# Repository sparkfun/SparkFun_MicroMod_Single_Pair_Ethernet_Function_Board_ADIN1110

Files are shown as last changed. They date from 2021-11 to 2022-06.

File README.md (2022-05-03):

SparkFun_MicroMod_Single_Pair_Ethernet_Function_Board_ADIN1110
========================================

SparkFun MicroMod Single Pair Ethernet Function Board - ADIN1110 (https://www.sparkfun.com/products/19038)

[*SparkFun MicroMod Single Pair Ethernet Function Board - ADIN1110 (COM-19038)*](https://www.sparkfun.com/products/19038)

A MicroMod Function Board that provides Single Pair Ethernet (SPE) using the Analog Devices ADIN1110 10BASE-T1L Ethernet MAC-PHY Transceiver. The ADIN1110 is an ultra-low power, single-port Single Pair Ethernet transceiver. It features an integrated media access control (MAC) interface to allow for direct connections with a host controller via a serial peripheral interface (SPI) at 10 Mbp/s full duplex. To top it off, the specified cable reach for edge nodes is up to 1700 meters.

Repository Contents
-------------------

* **/Documents** - Datasheet
* **/Hardware** - Eagle design files (.brd, .sch)

Documentation
-------------

* **[Hookup Guide](https://learn.sparkfun.com/tutorials/micromod-single-pair-ethernet-function-board---adin1110-hookup-guide)** - A basic Hookup Guide to get started with the MicroMod Single Pair Ethernet Function Board - ADIN1110.
* **[SparkFun ADIN1110 Arduino Library](https://github.com/sparkfun/SparkFun_ADIN1110_Arduino_Libary)** - An Arduino library for the SparkFun MicroMod Single Pair Ethernet Function Board - ADIN1110.

Product Versions
----------------

* [COM-19038](https://www.sparkfun.com/products/19038) - Initial release

Version History
---------------

* v1.0 - Initial Release

License Information
-------------------

This product is _**open source**_! 

Please review the LICENSE.md file for license information. 

If you have any questions or concerns on licensing, please contact technical support on our [SparkFun forums](https://forum.sparkfun.com/viewforum.php?f=152).

Distributed as-is; no warranty is given.

- Your friends at SparkFun.

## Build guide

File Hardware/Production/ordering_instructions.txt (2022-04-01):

panel size, 128x137mm
PCB thickness, 0.8mm
number of layers, 4
bevel, Gold Fingers + 45° Finger Chamfered
soldermask color, Red
silkscreen color, White
oz copper, 1oz
finish, ENIG
stencils, top
pcs per panel, 6
min trace width, 0.1524mm / 0.0060in
min drill size, 0.3048mm / 0.0120in

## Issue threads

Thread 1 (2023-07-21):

Incompatibility with Esp32 MicroMod Processor Board

shulltronics, 2023-07-21:
Hi Sparkfun!

One of the SPE design challenge participants here :)  I have started working with the hardware kits that you sent us, and I have discovered an issue with the compatibility of this board with the Esp32 processor board, which is somewhat surprising seeing as you explicitly sell them together in a kit.

The INT pin for this function board is pulled high via R24, and is broken out to the PWM1 pad of the MicroMod connector (pin 47 I think). On the Esp32 side, pulling this pin high interferes with some bootstrapping stuff, making it such that the MCU cannot be programmed while the boards are connected.

I'm also creating an issue over on the ESP side, which I will link to here, because ultimately I think that GPIO12 (or any of the bootstrap pins) shouldn't be routed to the connector, for sake of compatibility with future function boards; however, you might also consider moving this pin to another spot on the MircoMod connector that is more suitable for interrupts, like one of the Gx bus pins, D0, D1, or I2C_INT (not used on this board).

I just wanted to make you all aware of this, and start a discussion for others who might run into this issue. Thanks!

alin180493, 2023-08-14:
Hi shulltronics,
I am part of the SPE challenge as well. I have raised this issue with sparkfun about 2 months ago.
After some back and forth emails with them, the conclusion was that they do not have a Engineer assigned for this project or the challenge and that  this is not very high on the priority list.
From my side, the "project" I am going to do for the challenge is to document my experience on a dev board worth 180 dollars which is not working with their demo codes.
A shame that we couldn't experience this new technology and supposedly for a challenge they do not have a person in charge.
PS: i am in this SPE challenge as a hobbyist that wants to do something cool with this tech and not as a professional embedded systems engineer.
PS2: The Harting connectors on the board are not compatible the supposedly standard Amphenol or TE connectors without mods...Amphenol and TE connectors are corss compatible.
Kind regards,
Alin

shulltronics, 2023-08-15:
Hi Alin,

Thanks for contributing to this issue :) It's sad that there is no one from SparkFun to help us with this -- especially considering an explicit issue like this with a product that they are current selling. Thanks for sharing about the connector compatibility.. part of my work on the challenge is a new hardware design so that is useful information.

alin180493, 2023-08-15:
Hi,

I have added some screenshot and pictures with the part numbers i have used to tryout the connector and also, to show the difference between them. You can see that on the spe board the connector has a shallower larger hole than the other 2 types of connector.

Feel free to use the images as reference if you find them helpful.

Kind regards,
Alin

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

lewispg228, 2023-08-16:
Hi Carsten and Alin,
Thanks for bringing this issue to our attention. Sorry for the inconvenience. We would recommend removing R22 from the design, or cutting the nearby trace to effectively remove the pullup from the circuit. Note, once this modification is done, then you will need to actively control that control pin on the processor board in your code. During your setup() make sure to include an extra line of code to enable that GPIO:

`pinMode(PWM1, INPUT_PULLUP);`

This will ensure that the function board's power vreg is enabled.

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

As for the cables, we only carry Harting cables and connectors, so we are unable to test with other branded connectors. We have our 0.5m cable available. Sorry we don't carry anything longer or the connector on it's own. We hope the modification you came up with to enlarge the hole will work well enough to get you through the project.

[https://www.sparkfun.com/products/19312](https://www.sparkfun.com/products/19312)

Hope this helps and let us know how it goes. -Pete Lewis

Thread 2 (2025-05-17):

ADIN1100 to ADIN1110 to give internet to MicroMOD?

bhupiister, 2025-05-17:
Is there a possibility to use ADIN1100 <==> ADIN1110 to give internet to MicroMOD boards?
Some sort of driver work can make it possible?

daveismith, 2025-05-22:
It's possible, but you need to have a an IP stack which SparkFun doesn't provide. If you have the right adaptor, see https://www.sg-electronic-systems.com/adin1110-linux-kernel/ for how to connect this as an interface to a Raspberry Pi. You can then set up the proper routing on a Pi. Alternatively Arrow sells (or maybe used to sell) a media converter that you can plug ethernet & USB-C for power on one side and get SPE out the other. See https://www.arrow.com/en/products/10base-t1l-mc/einfochips-limited.

For the embedded space, I got some sort of a driver for this working on the ESP32 (with esp-idf) back a few years ago but I wasn't sure about publishing it due to AD's licensing terms. Now it's likely not compatible with current versions of the ESP-IDF. If you use rust, the embassy framework has a driver that works for this and gives IP layer access (see https://docs.embassy.dev/embassy-net-adin1110/git/default/index.html) - note you need to solder jumper `SPICFG1`.

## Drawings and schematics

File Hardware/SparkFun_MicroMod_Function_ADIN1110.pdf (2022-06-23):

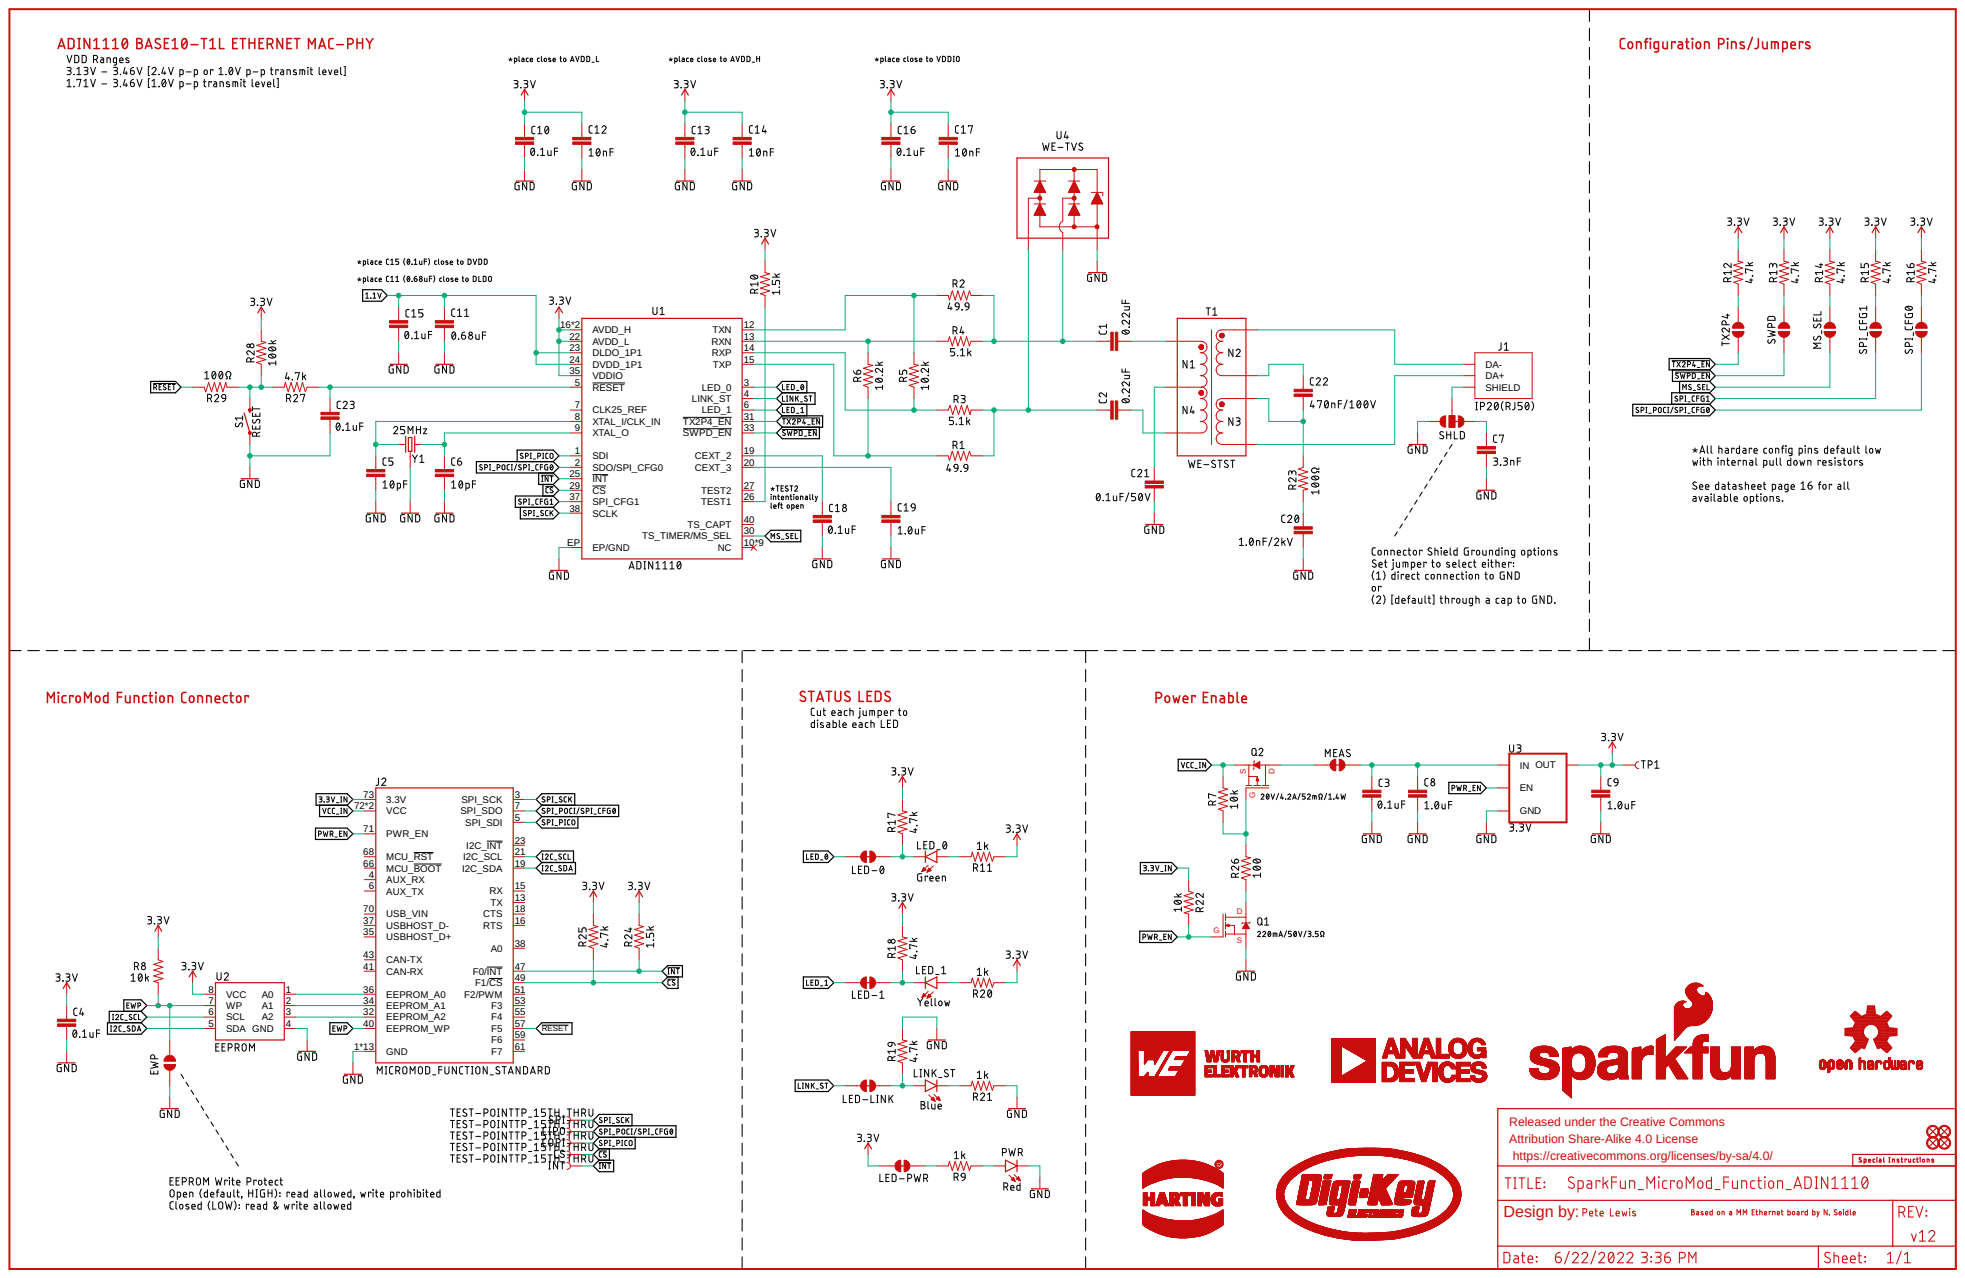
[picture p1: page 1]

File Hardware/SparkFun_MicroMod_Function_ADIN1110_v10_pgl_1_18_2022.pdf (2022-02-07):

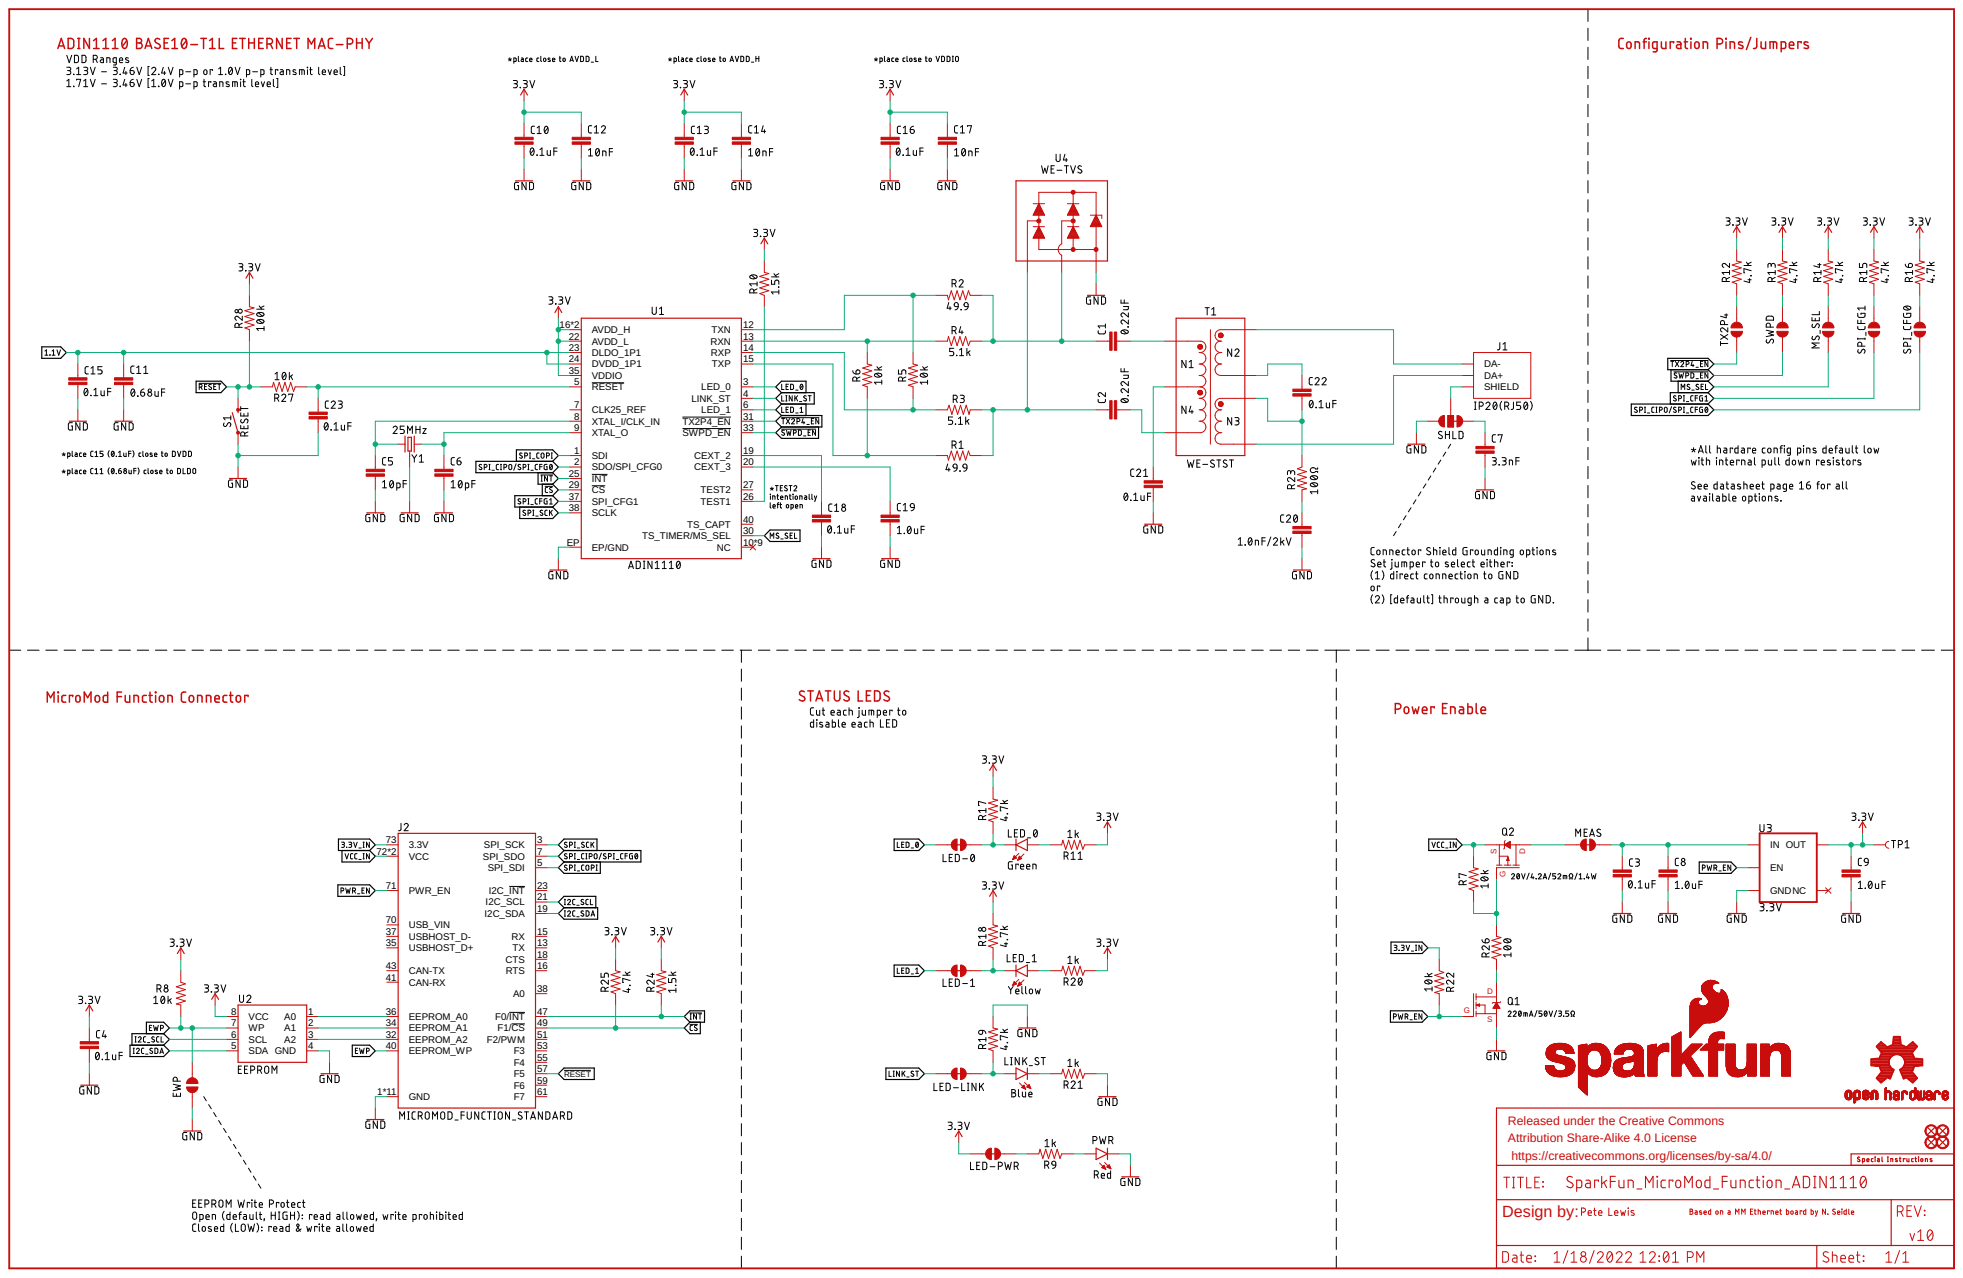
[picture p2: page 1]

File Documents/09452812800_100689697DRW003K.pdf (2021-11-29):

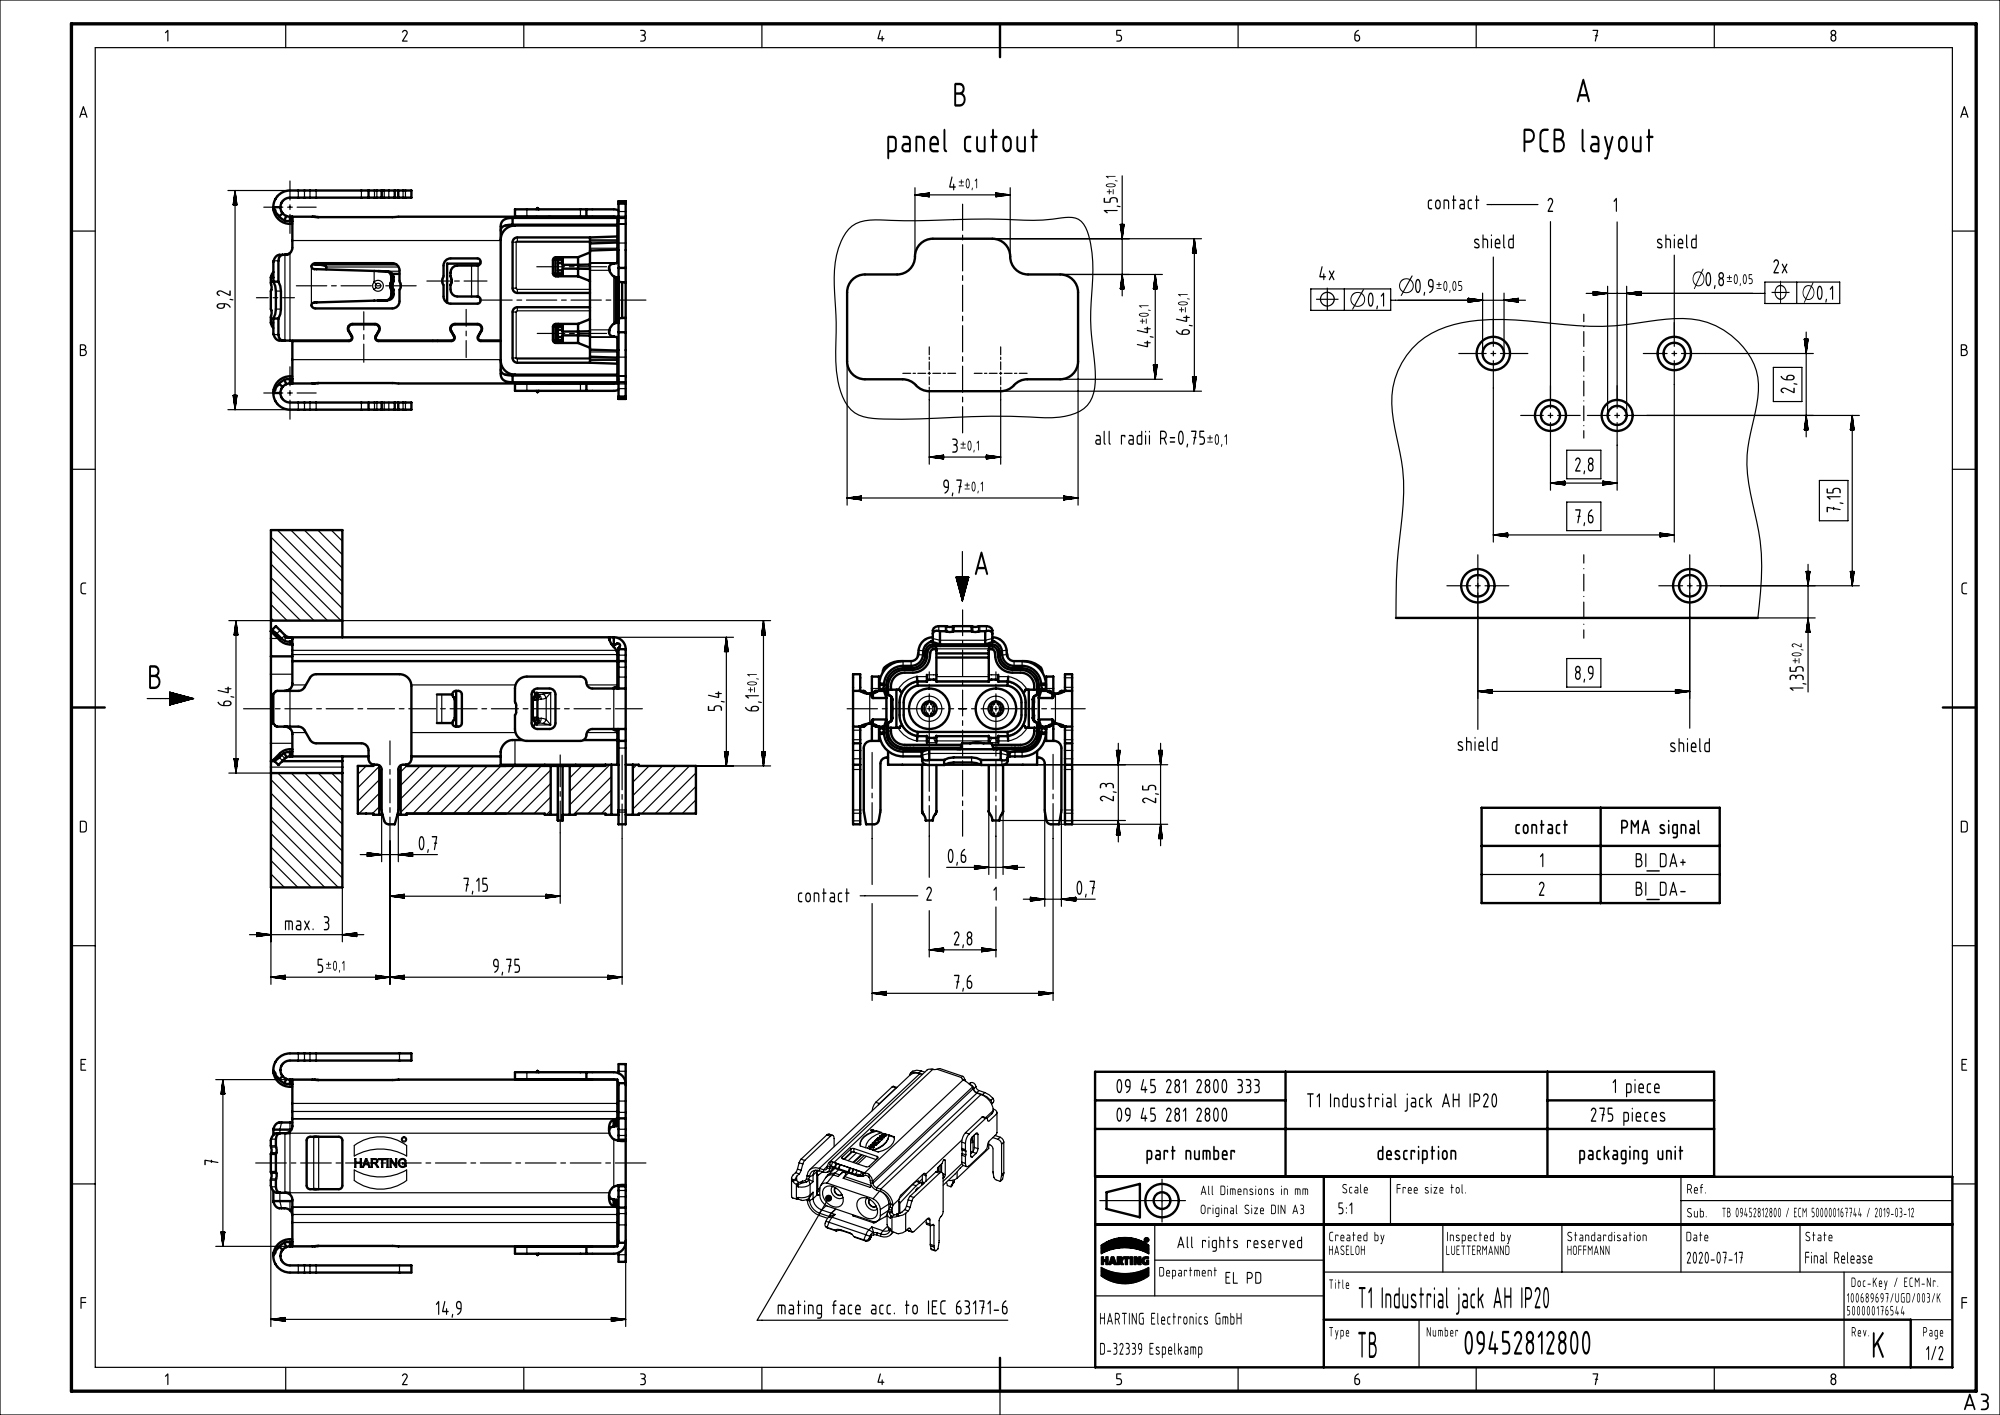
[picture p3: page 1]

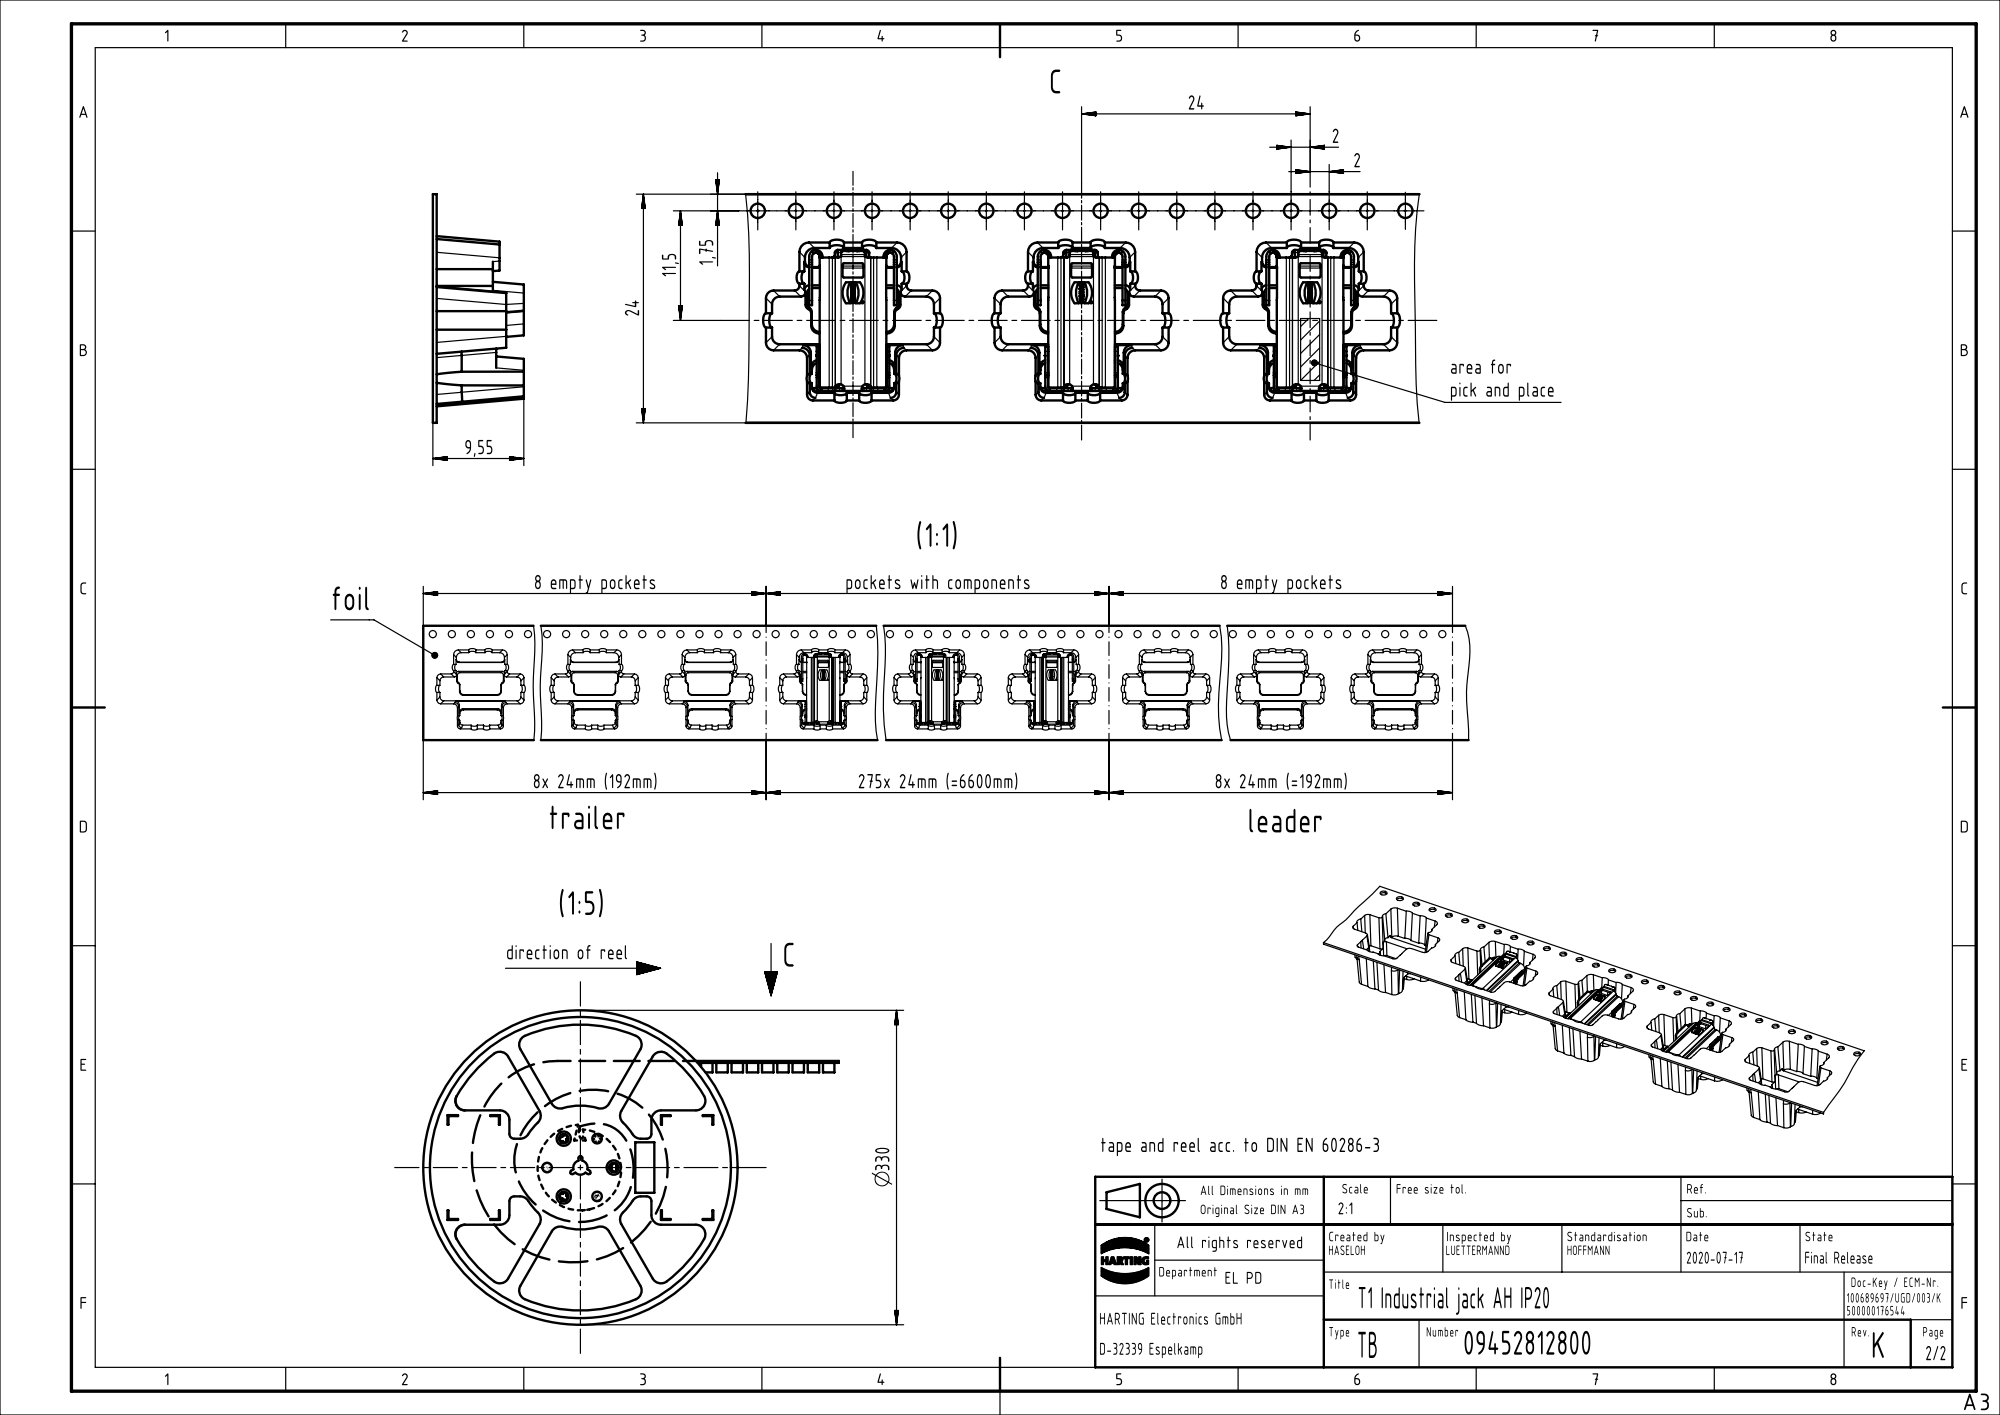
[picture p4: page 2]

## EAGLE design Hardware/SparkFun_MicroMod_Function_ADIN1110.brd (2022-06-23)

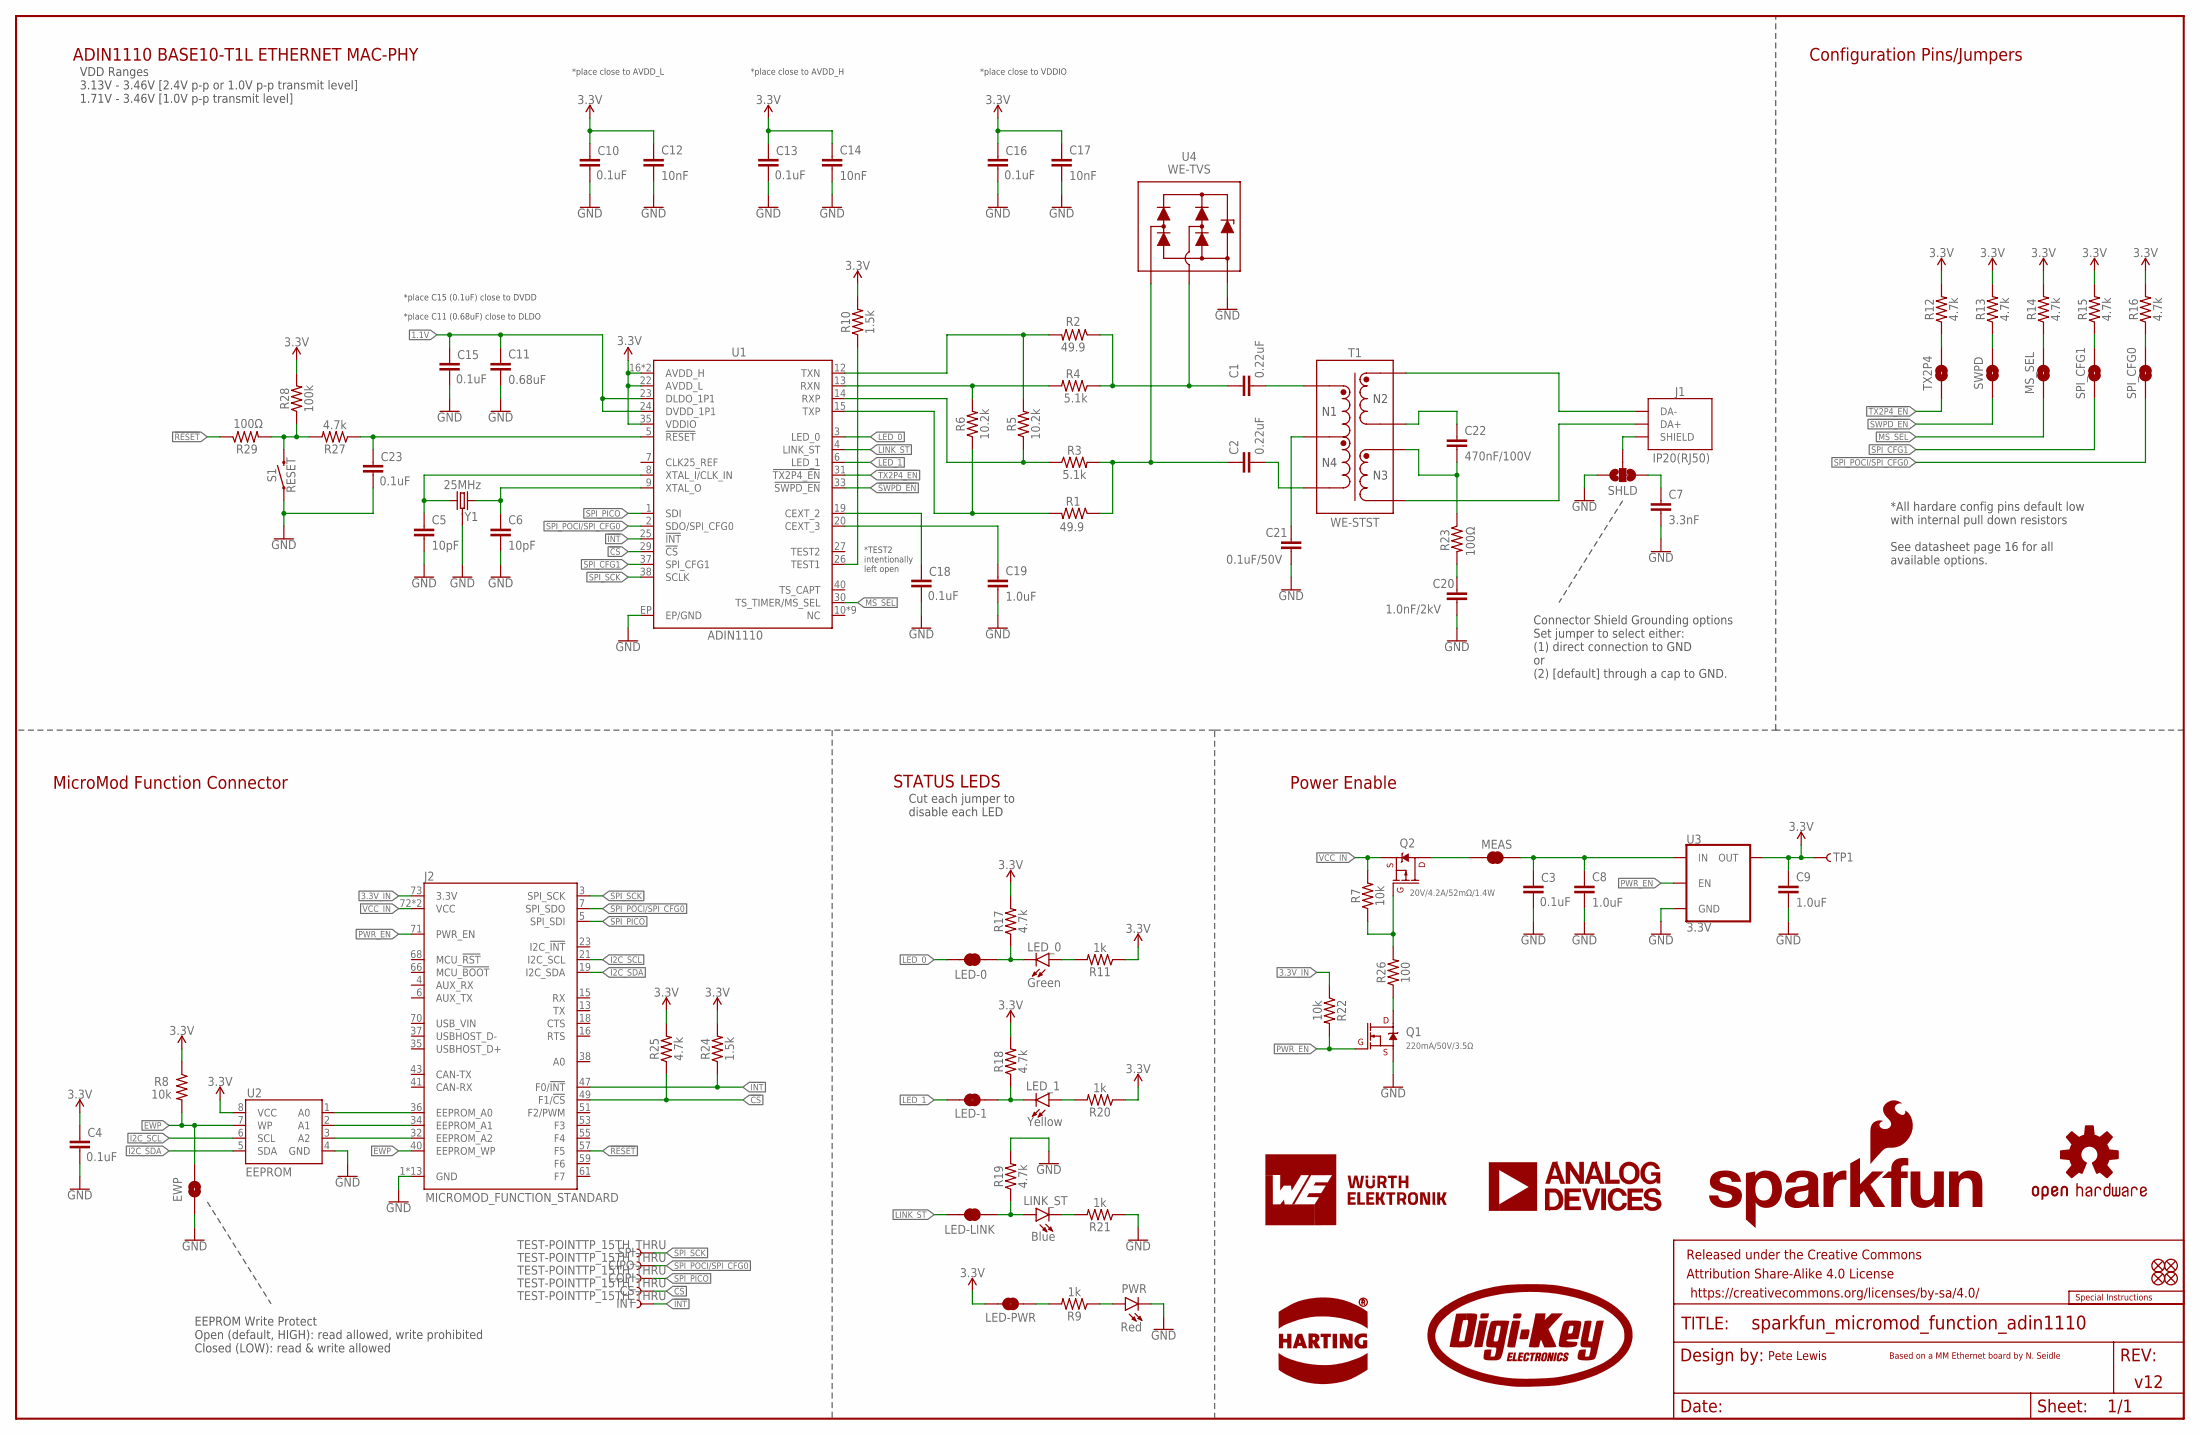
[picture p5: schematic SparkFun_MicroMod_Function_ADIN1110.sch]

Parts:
C1, C2: 0.22uF; 0603
C3, C4: 0.1uF; 0603
C5, C6: 10pF; 0603
C7: 3.3nF; 0603
C8, C9: 1.0uF; 0603
C10, C13, C15, C16, C18, C23: 0.1uF; 0402-TIGHT
C11: 0.68uF; 0603
C12, C14, C17: 10nF; 0402-TIGHT
C19: 1.0uF; 0402-TIGHT
C20: 1.0nF/2kV; 1206
C21: 0.1uF/50V; 0603
C22: 470nF/100V; 0805
CIPO: TEST-POINTTP_15TH_THRU; TP_15TH
COPI: TEST-POINTTP_15TH_THRU; TP_15TH
CS: TEST-POINTTP_15TH_THRU; TP_15TH
EWP: JUMPER-SMT_2_NO_SILK; SMT-JUMPER_2_NO_SILK
FD1, FD2, FD3, FD4: FIDUCIALUFIDUCIAL; FIDUCIAL-MICRO
FRAME1: FRAME-LEDGER; CREATIVE_COMMONS
INT: TEST-POINTTP_15TH_THRU; TP_15TH
J1: IP20(RJ50); T1_INDUSTRIAL_JACK_AH_IP20
J2: MICROMOD_FUNCTION_STANDARD; M.2-CARD-E-22_FUNCTION_STANDARD
LED-0, LED-1: JUMPER-SMT_2_NC_TRACE_SILK; SMT-JUMPER_2_NC_TRACE_SILK
LED-LINK: JUMPER-SMT_2_NC_TRACE_SILK; SMT-JUMPER_2_NC_TRACE_SILK
LED-PWR: JUMPER-SMT_2_NC_TRACE_SILK; SMT-JUMPER_2_NC_TRACE_SILK
LED_0: Green; LED-0603
LED_1: Yellow; LED-0603
LINK_ST: Blue; LED-0603
LOGO1: SFE_LOGO_NAME_FLAME.1_INCH; SFE_LOGO_NAME_FLAME_.1
LOGO2: SPECIAL_INSTRUCTIONS-ORDERING; ORDERING_INSTRUCTIONS
LOGO3: OSHW-LOGOMINI; OSHW-LOGO-MINI
MEAS: JUMPER-COMBO_2_NC_TRACE; COMBO-JUMPER_2_NC_TRACE
MS_SEL: JUMPER-SMT_2_NO_SILK; SMT-JUMPER_2_NO_SILK
PWR: Red; LED-0603
Q1: 220mA/50V/3.5Ω; SOT23-3
Q2: 20V/4.2A/52mΩ/1.4W; SOT23-3
R1, R2: 49.9; 0603
R3, R4: 5.1k; 0402-TIGHT
R5, R6: 10.2k; 0402-TIGHT
R7, R8, R22: 10k; 0603
R9, R11, R20, R21: 1k; 0402-TIGHT
R10, R24: 1.5k; 0603
R12, R13, R14, R15, R16, R17, R18, R19, R25: 4.7k; 0402-TIGHT
R23, R29: 100Ω; 0603
R26: 100; 0603
R27: 4.7k; 0603
R28: 100k; 0402-TIGHT
S1: RESET; TACTILE_SWITCH_SMD_5.2MM
SHLD: JUMPER-SMT_3_1-NC_TRACE_SILK; SMT-JUMPER_3_1-NC_TRACE_SILK
SPI: TEST-POINTTP_15TH_THRU; TP_15TH
SPI_CFG0, SPI_CFG1: JUMPER-SMT_2_NO_SILK; SMT-JUMPER_2_NO_SILK
SWPD: JUMPER-SMT_2_NO_SILK; SMT-JUMPER_2_NO_SILK
T1: WE-STST; WE_STST_TRANSFORMER_1:1_SMD_3.2X4.7MM_74930030
TP1: TEST-POINT3X4; PAD.03X.04
TX2P4: JUMPER-SMT_2_NO_SILK; SMT-JUMPER_2_NO_SILK
U1: ADIN1110; LFCSP-40
U2: EEPROM; SO08
U3: 3.3V; SOT23-5
U4: WE-TVS; WE_TVS_1.0X1.2MM
U$2: HARTING_LOGO; HARTING_LOGO_9MM
U$5: DIGIKEY_LOGO
U$19: WURTH_LOGO; WURTH_LOGO_9MM
U$33: ANALOG_DEVICES_LOGO; ANALOG_DEVICE_LOGO_9MM
Y1: 25MHz; CRYSTAL-SMD-2.0X1.6MM-WE

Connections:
1.1V: C11.1, C15.1, U1.23 (DLDO_1P1), U1.24 (DVDD_1P1)
3.3V: C4.1, C9.1, C10.1, C12.1, C13.1, C14.1, C16.1, C17.1, LED-PWR.2, R8.1, R10.2, R11.1, R12.2, R13.2, R14.2, R15.2, R16.2, R17.2, R18.2, R20.1, R24.2, R25.2, R28.2, TP1.1, U1.16 (AVDD_H), U1.17 (AVDD_H), U1.22 (AVDD_L), U1.35 (VDDIO), U2.8 (VCC), U3.5 (OUT)
3.3V_IN: J2.73 (3.3V), R22.1
!CS!: CS.1, J2.49 (F1/!CS!), R25.1, U1.29 (!CS!)
!INT!: INT.1, J2.47 (F0/!INT!), R24.1, U1.25 (!INT!)
!RESET!: J2.57 (F5), R29.1
!SWPD_EN!: SWPD.1, U1.33 (!SWPD_EN!)
!TX2P4_EN!: TX2P4.1, U1.31 (!TX2P4_EN!)
A0: J2.36 (EEPROM_A0), U2.1 (A0)
A1: J2.34 (EEPROM_A1), U2.2 (A1)
A2: J2.32 (EEPROM_A2), U2.3 (A2)
DA+: J1.1 (DA+), T1.7
DA-: J1.2 (DA-), T1.6
EWP: EWP.2, J2.40 (EEPROM_WP), R8.2, U2.7 (WP)
GND: C3.2, C4.2, C5.2, C6.2, C7.2, C8.2, C9.2, C10.2, C11.2, C12.2, C13.2, C14.2, C15.2, C16.2, C17.2, C18.2, C19.2, C20.2, C21.2, C23.2, EWP.1, J2.1 (GND), J2.2 (GND), J2.8 (GND), J2.33 (GND), J2.39 (GND), J2.45 (GND), J2.75 (GND), J2.GND1 (GND), J2.GND2 (GND), J2.GND3 (GND), J2.GND4 (GND), J2.GND5 (GND), J2.GND6 (GND), PWR.C, Q1.2 (S), R19.2, R21.1, S1.1, SHLD.1, U1.EP (EP/GND), U2.4 (GND), U3.2 (GND), U4.3, Y1.2 (GND), Y1.4 (GND)
I2C_SCL: J2.21 (I2C_SCL), U2.6 (SCL)
I2C_SDA: J2.19 (I2C_SDA), U2.5 (SDA)
LED_0: LED-0.2, U1.3 (LED_0)
LED_1: LED-1.2, U1.6 (LED_1)
LINK_ST: LED-LINK.2, U1.4 (LINK_ST)
MS_SEL: MS_SEL.1, U1.30 (TS_TIMER/MS_SEL)
unnamed: MEAS.1, MEAS.3 (1), Q2.3 (D)
unnamed: C3.1, C8.1, MEAS.2, MEAS.4 (2), U3.1 (IN)
unnamed: C21.1, T1.5
unnamed: C22.1, T1.4
unnamed: LED-LINK.1, LINK_ST.A, R19.1
unnamed: LED-1.1, LED_1.C, R18.1
unnamed: C22.2, R23.1, T1.3
unnamed: C20.1, R23.2
unnamed: LED-0.1, LED_0.C, R17.1
unnamed: Q1.3 (D), R26.1
unnamed: Q2.1 (G), R7.1, R26.2
unnamed: C5.1, U1.8 (XTAL_I/CLK_IN), Y1.1
unnamed: C23.1, R27.1, U1.5 (!RESET!)
unnamed: C6.1, U1.9 (XTAL_O), Y1.3 (2)
unnamed: R27.2, R28.1, R29.2, S1.3 (2)
unnamed: R10.1, U1.26 (TEST1)
unnamed: LED-PWR.1, R9.2
unnamed: PWR.A, R9.1
unnamed: C18.1, U1.19 (CEXT_2)
unnamed: C19.1, U1.20 (CEXT_3)
unnamed: LED_0.A, R11.2
unnamed: C1.1, R2.1, R4.1, U4.2, U4.5 (2)
unnamed: MS_SEL.2, R14.1
unnamed: R13.1, SWPD.2
unnamed: R12.1, TX2P4.2
unnamed: R16.1, SPI_CFG0.2
unnamed: R15.1, SPI_CFG1.2
unnamed: LED_1.A, R20.2
unnamed: C2.1, R1.1, R3.2, U4.1, U4.6 (1)
unnamed: C1.2, T1.1
unnamed: LINK_ST.C, R21.2
unnamed: C2.2, T1.2
unnamed: R4.2, R6.2, U1.13 (RXN)
unnamed: R3.1, R5.1, U1.14 (RXP)
unnamed: R1.2, R6.1, U1.15 (TXP)
unnamed: R2.2, R5.2, U1.12 (TXN)
unnamed: C7.1, SHLD.3
unnamed: J1.S1 (SHIELD), J1.S2 (SHIELD), J1.S3 (SHIELD), J1.S4 (SHIELD), SHLD.2
PWR_EN: J2.71 (PWR_EN), Q1.1 (G), R22.2, U3.3 (EN)
SPI_CFG1: SPI_CFG1.1, U1.37 (SPI_CFG1)
SPI_PICO: COPI.1, J2.5 (SPI_SDI), U1.1 (SDI)
SPI_POCI/SPI_CFG0: CIPO.1, J2.7 (SPI_SDO), SPI_CFG0.1, U1.2 (SDO/SPI_CFG0)
SPI_SCK: J2.3 (SPI_SCK), SPI.1, U1.38 (SCLK)
VCC_IN: J2.72 (VCC), J2.74 (VCC), Q2.2 (S), R7.2

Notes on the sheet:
MicroMod Function Connector
Pete Lewis
v12
ADIN1110 BASE10-T1L ETHERNET MAC-PHY
Power Enable
Based on a MM Ethernet board by N. Seidle
*place C15 (0.1uF) close to DVDD *place C11 (0.68uF) close to DLDO
*place close to AVDD_L
*place close to AVDD_H
*place close to VDDIO
*TEST2 intentionally left open
*All hardare config pins default low with internal pull down resistors See datasheet page 16 for all available options.
STATUS LEDS
Configuration Pins/Jumpers
VDD Ranges 3.13V - 3.46V [2.4V p-p or 1.0V p-p transmit level] 1.71V - 3.46V [1.0V p-p transmit level]
EEPROM Write Protect Open (default, HIGH): read allowed, write prohibited Closed (LOW): read & write allowed
Connector Shield Grounding options Set jumper to select either: (1) direct connection to GND or (2) [default] through a cap to GND.
Cut each jumper to disable each LED

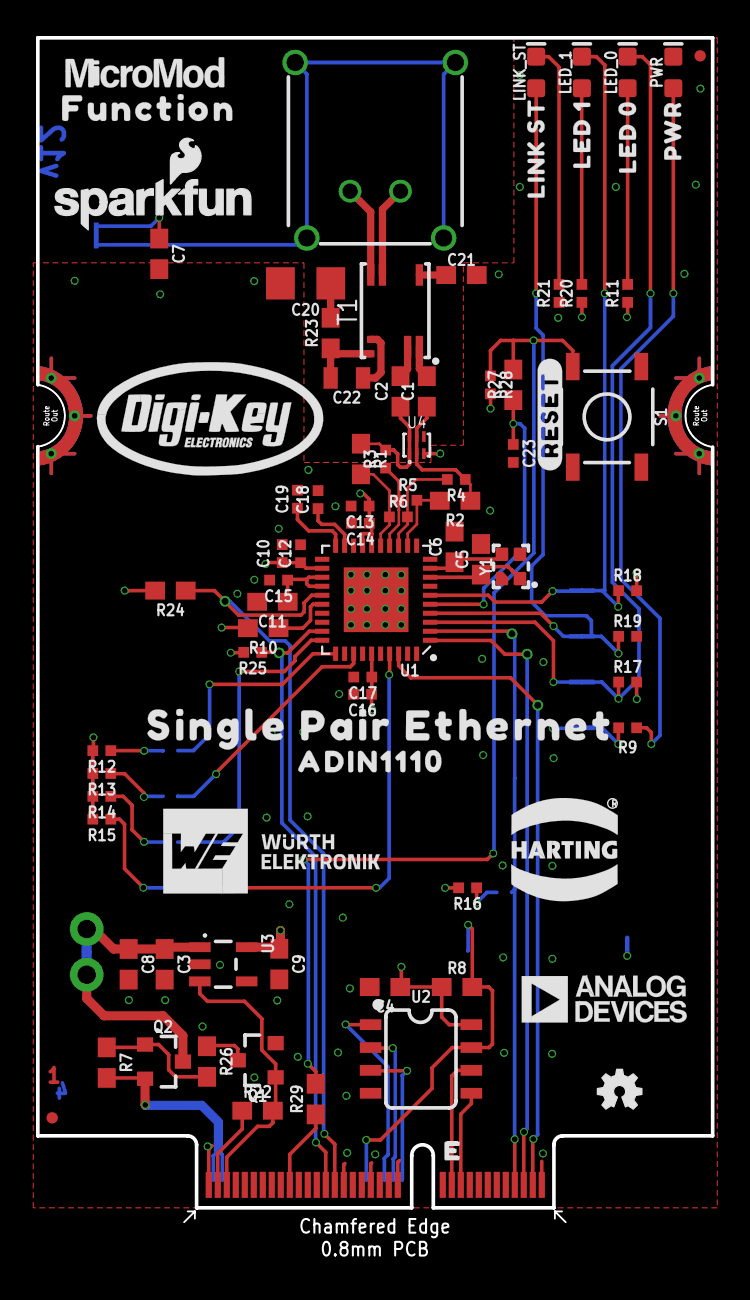
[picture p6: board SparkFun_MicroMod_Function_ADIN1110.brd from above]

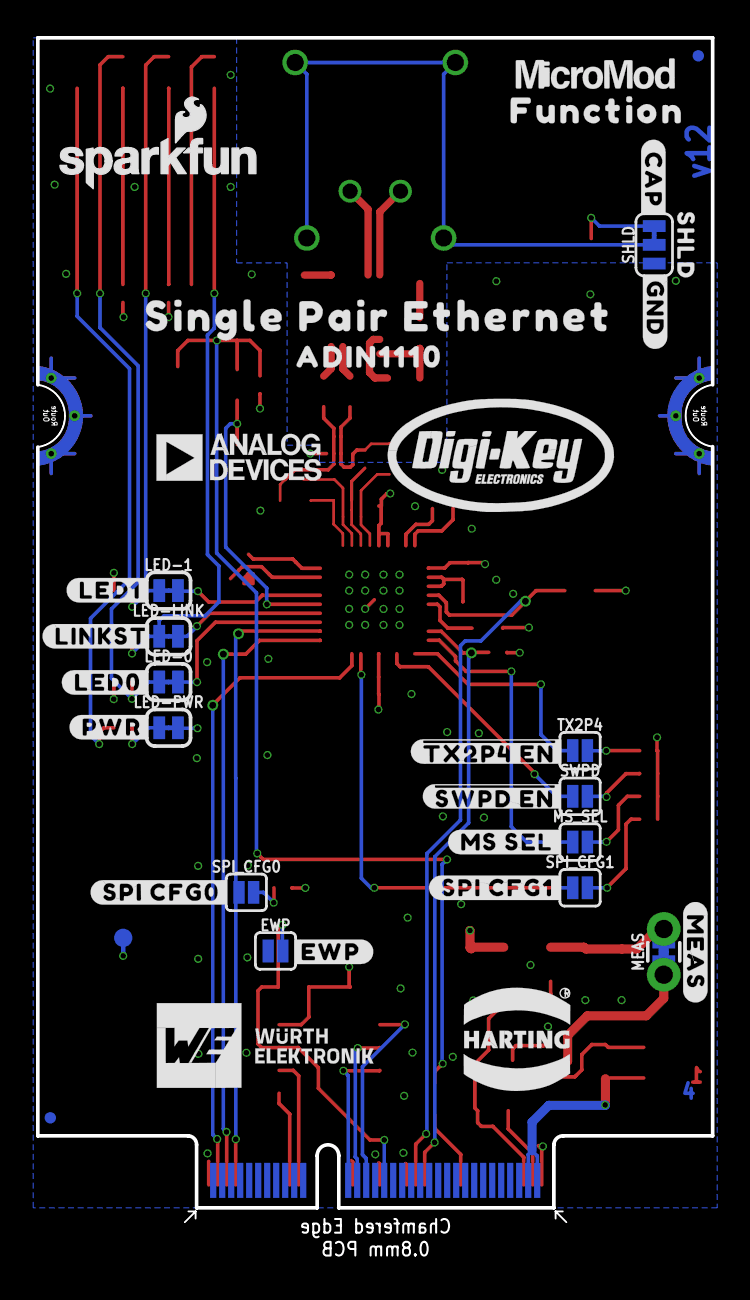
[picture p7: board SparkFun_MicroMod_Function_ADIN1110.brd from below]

Board: 4 copper layers, 37.5 x 65.8 mm, 129 parts (38 on the bottom side), 65 nets.

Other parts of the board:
U$1: #RESET#0
U$4, U$21: ADIN11100
U$6: #PWR#19
U$7: PWR0
U$8: SHLD11
U$9: #EWP#18
U$10: #LED0#20
U$11: #GND#16
U$12: #CAP#17
U$13: ##TX2P4_EN##4
U$14: #SPI_CFG1#0
U$15: #MS_SEL#2
U$16: #SPI_CFG0#0
U$17, U$18: SINGLE_PAIR_ETHERNET0
U$20: ANALOG_DEVICE_LOGO_9MM
U$22: ##SWPD_EN##4
U$23: LED_03
U$24, U$26: FUNCTION0
U$25: LED_14
U$27: LINK_ST15
U$28: #MEAS#3
U$29: #LED1#21
U$30: HARTING_LOGO_9MM
U$31: #LINKST#2
U$32: WURTH_LOGO_9MM
U$34: DIGIKEY_LOGO
U$35: SFE_LOGO_NAME_FLAME_.1
U$37, U$63: MICROMOD_LOGO_.35

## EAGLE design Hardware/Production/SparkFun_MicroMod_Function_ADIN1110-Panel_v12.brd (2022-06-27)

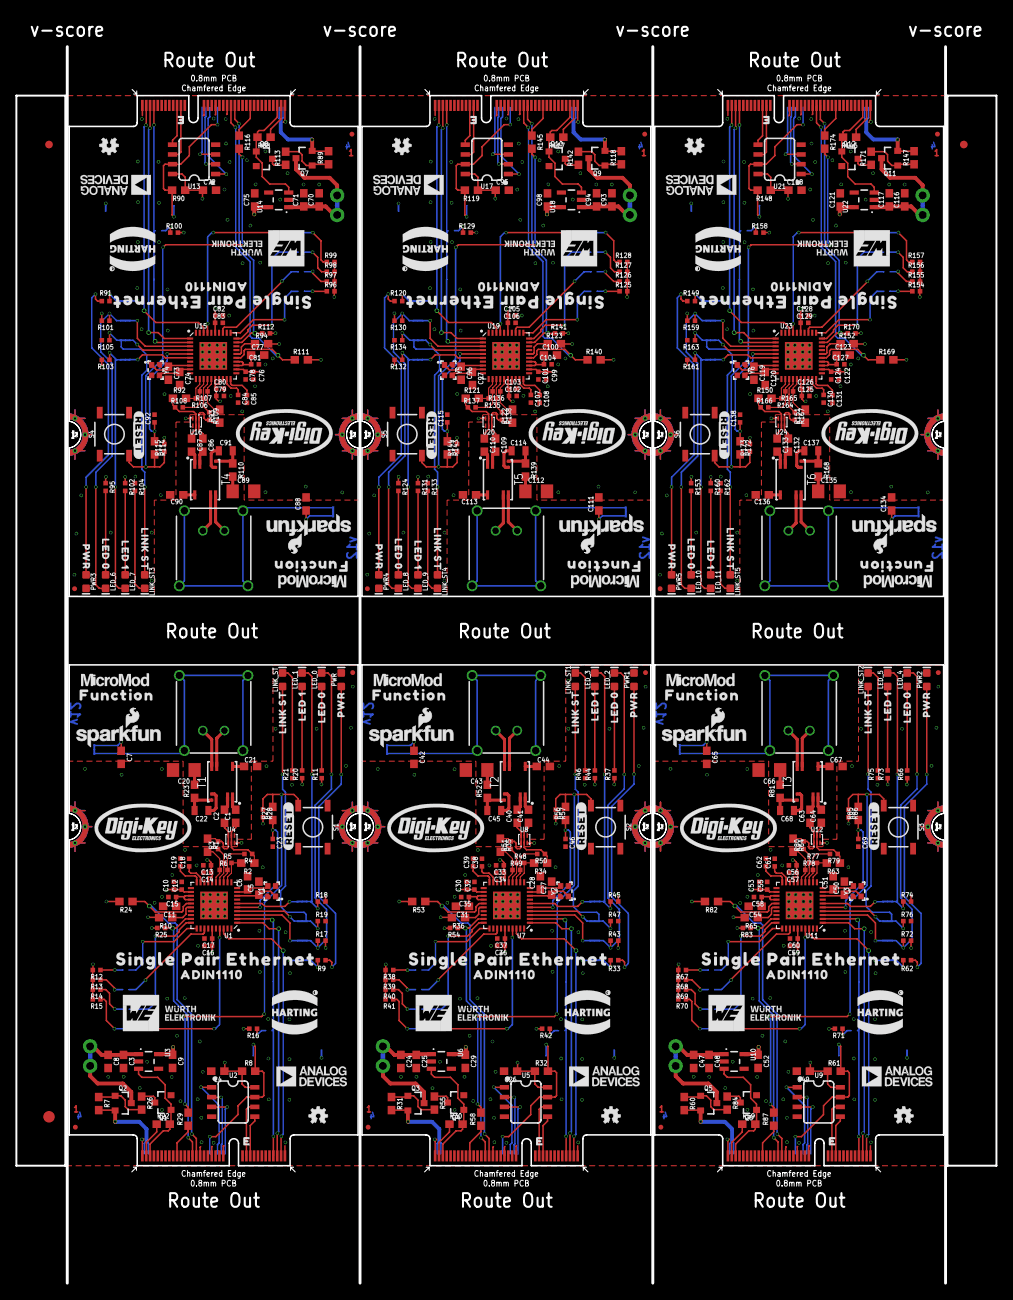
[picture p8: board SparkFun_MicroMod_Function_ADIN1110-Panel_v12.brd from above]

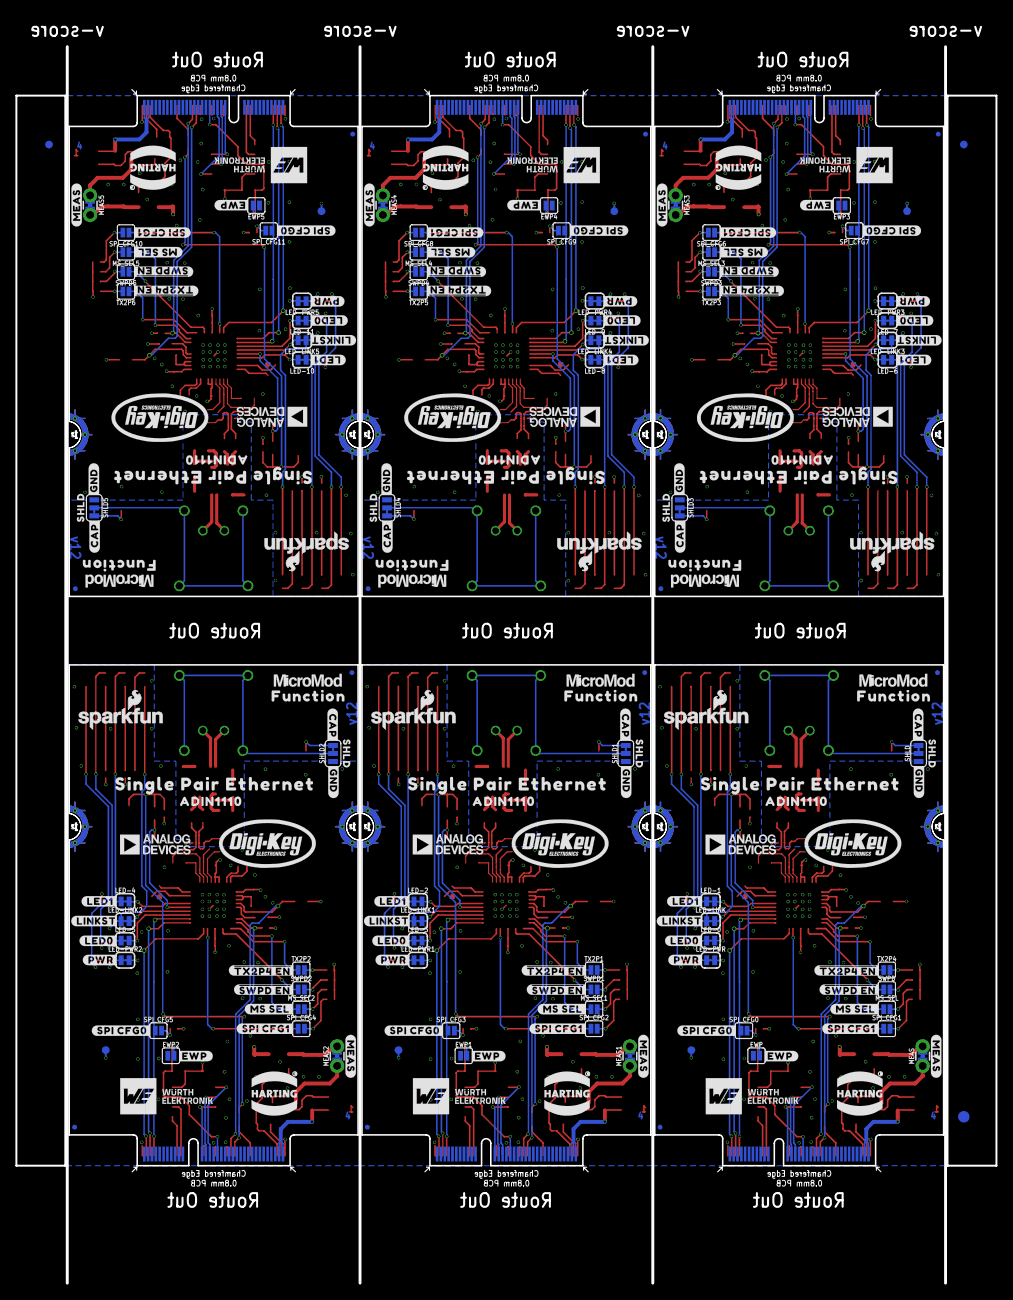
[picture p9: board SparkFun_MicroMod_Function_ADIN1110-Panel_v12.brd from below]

Board: 4 copper layers, 127.2 x 160.5 mm, 768 parts (231 on the bottom side), 390 nets.

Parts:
C1, C2, C40, C41, C63, C64, C86, C87, C109, C110, C132, C133: 0.22uF; 0603
C3, C4, C25, C26, C48, C49, C71, C72, C94, C95, C117, C118: 0.1uF; 0603
C5, C6, C27, C28, C50, C51, C73, C74, C96, C97, C119, C120: 10pF; 0603
C7, C42, C65, C88, C111, C134: 3.3nF; 0603
C8, C9, C24, C29, C47, C52, C70, C75, C93, C98, C116, C121: 1.0uF; 0603
C10, C13, C15, C16, C18, C23, C30, C33, C35, C36, C38, C46, C53, C56, C58, C59, C61, C69, C76, C79, C81, C82, C84, C92, C99, C102, C104, C105, C107, C115, C122, C125, C127, C128, C130, C138: 0.1uF; 0402-TIGHT
C11, C31, C54, C77, C100, C123: 0.68uF; 0603
C12, C14, C17, C32, C34, C37, C55, C57, C60, C78, C80, C83, C101, C103, C106, C124, C126, C129: 10nF; 0402-TIGHT
C19, C39, C62, C85, C108, C131: 1.0uF; 0402-TIGHT
C20, C43, C66, C89, C112, C135: 1.0nF/2kV; 1206
C21, C44, C67, C90, C113, C136: 0.1uF/50V; 0603
C22, C45, C68, C91, C114, C137: 470nF/100V; 0805
CIPO, CIPO1, CIPO2, CIPO3, CIPO4, CIPO5: TEST-POINTTP_15TH_THRU; TP_15TH
COPI, COPI1, COPI2, COPI3, COPI4, COPI5: TEST-POINTTP_15TH_THRU; TP_15TH
CS, CS1, CS2, CS3, CS4, CS5: TEST-POINTTP_15TH_THRU; TP_15TH
E$1, E$2, E$3, E$4: FIDUCIAL-1X2
E$5, E$6: FIDUCIAL-1.5X3
EWP, EWP1, EWP2, EWP3, EWP4, EWP5: JUMPER-SMT_2_NO_SILK; SMT-JUMPER_2_NO_SILK
FD1, FD2, FD3, FD4, FD5, FD6, FD7, FD8, FD9, FD10, FD11, FD12, FD13, FD14, FD15, FD16, FD17, FD18, FD19, FD20, FD21, FD22, FD23, FD24: FIDUCIALUFIDUCIAL; FIDUCIAL-MICRO
INT, INT1, INT2, INT3, INT4, INT5: TEST-POINTTP_15TH_THRU; TP_15TH
J1, J4, J6, J8, J10, J12: IP20(RJ50); T1_INDUSTRIAL_JACK_AH_IP20
J2, J3, J5, J7, J9, J11: MICROMOD_FUNCTION_STANDARD; M.2-CARD-E-22_FUNCTION_STANDARD
LED-0, LED-1, LED-2, LED-3, LED-4, LED-5, LED-6, LED-7, LED-8, LED-9, LED-10, LED-11: JUMPER-SMT_2_NC_TRACE_SILK; SMT-JUMPER_2_NC_TRACE_SILK
LED-LINK, LED-LINK1, LED-LINK2, LED-LINK3, LED-LINK4, LED-LINK5: JUMPER-SMT_2_NC_TRACE_SILK; SMT-JUMPER_2_NC_TRACE_SILK
LED-PWR, LED-PWR1, LED-PWR2, LED-PWR3, LED-PWR4, LED-PWR5: JUMPER-SMT_2_NC_TRACE_SILK; SMT-JUMPER_2_NC_TRACE_SILK
LED_0, LED_2, LED_4, LED_6, LED_8, LED_10: Green; LED-0603
LED_1, LED_3, LED_5, LED_7, LED_9, LED_11: Yellow; LED-0603
LINK_ST, LINK_ST1, LINK_ST2, LINK_ST3, LINK_ST4, LINK_ST5: Blue; LED-0603
LOGO1, LOGO4, LOGO6, LOGO8, LOGO10, LOGO12: SFE_LOGO_NAME_FLAME.1_INCH; SFE_LOGO_NAME_FLAME_.1
LOGO2, LOGO3, LOGO5, LOGO7, LOGO9, LOGO11: OSHW-LOGOMINI; OSHW-LOGO-MINI
MEAS, MEAS1, MEAS2, MEAS3, MEAS4, MEAS5: JUMPER-COMBO_2_NC_TRACE; COMBO-JUMPER_2_NC_TRACE
MS_SEL, MS_SEL1, MS_SEL2, MS_SEL3, MS_SEL4, MS_SEL5: SMT-JUMPER_2_NO_SILK
PWR, PWR1, PWR2, PWR3, PWR4, PWR5: Red; LED-0603
Q1, Q4, Q6, Q8, Q10, Q12: 220mA/50V/3.5Ω; SOT23-3
Q2, Q3, Q5, Q7, Q9, Q11: 20V/4.2A/52mΩ/1.4W; SOT23-3
R1, R2, R34, R35, R63, R64, R92, R93, R121, R122, R150, R151: 49.9; 0603
R3, R4, R50, R51, R79, R80, R108, R109, R137, R138, R166, R167: 5.1k; 0402-TIGHT
R5, R6, R48, R49, R77, R78, R106, R107, R135, R136, R164, R165: 10.2k; 0402-TIGHT
R7, R8, R22, R30, R31, R32, R59, R60, R61, R88, R89, R90, R117, R118, R119, R146, R147, R148: 10k; 0603
R9, R11, R20, R21, R33, R37, R44, R46, R62, R66, R73, R75, R91, R95, R102, R104, R120, R124, R131, R133, R149, R153, R160, R162: 1k; 0402-TIGHT
R10, R24, R36, R53, R65, R82, R94, R111, R123, R140, R152, R169: 1.5k; 0603
R12, R13, R14, R15, R16, R17, R18, R19, R25, R38, R39, R40, R41, R42, R43, R45, R47, R54, R67, R68, R69, R70, R71, R72, R74, R76, R83, R96, R97, R98, R99, R100, R101, R103, R105, R112, R125, R126, R127, R128, R129, R130, R132, R134, R141, R154, R155, R156, R157, R158, R159, R161, R163, R170: 4.7k; 0402-TIGHT
R23, R29, R52, R58, R81, R87, R110, R116, R139, R145, R168, R174: 100Ω; 0603
R26, R55, R84, R113, R142, R171: 100; 0603
R27, R56, R85, R114, R143, R172: 4.7k; 0603
R28, R57, R86, R115, R144, R173: 100k; 0402-TIGHT
S1, S2, S3, S4, S5, S6: RESET; TACTILE_SWITCH_SMD_5.2MM
SHLD, SHLD1, SHLD2, SHLD3, SHLD4, SHLD5: SMT-JUMPER_3_1-NC_TRACE_SILK
SPI, SPI1, SPI2, SPI3, SPI4, SPI5: TEST-POINTTP_15TH_THRU; TP_15TH
SPI_CFG0, SPI_CFG1, SPI_CFG2, SPI_CFG3, SPI_CFG4, SPI_CFG5, SPI_CFG6, SPI_CFG7, SPI_CFG8, SPI_CFG9, SPI_CFG10, SPI_CFG11: SMT-JUMPER_2_NO_SILK
SWPD, SWPD1, SWPD2, SWPD3, SWPD4, SWPD5: SMT-JUMPER_2_NO_SILK
T1, T2, T3, T4, T5, T6: WE-STST; WE_STST_TRANSFORMER_1:1_SMD_3.2X4.7MM_74930030
TP1, TP2, TP3, TP4, TP5, TP6: TEST-POINT3X4; PAD.03X.04
TX2P1, TX2P2, TX2P3, TX2P4, TX2P5, TX2P6: SMT-JUMPER_2_NO_SILK
U1, U7, U11, U15, U19, U23: ADIN1110; LFCSP-40
U2, U5, U9, U13, U17, U21: EEPROM; SO08
U3, U6, U10, U14, U18, U22: 3.3V; SOT23-5
U4, U8, U12, U16, U20, U24: WE-TVS; WE_TVS_1.0X1.2MM
U$1, U$42, U$79, U$115, U$151, U$187: #RESET#0
U$2, U$71, U$107, U$143, U$179, U$215: HARTING_LOGO; HARTING_LOGO_9MM
U$3, U$36, U$37, U$63, U$73, U$74, U$109, U$110, U$145, U$146, U$181, U$182: MICROMOD_LOGO_.35
U$4, U$21, U$41, U$47, U$78, U$84, U$114, U$120, U$150, U$156, U$186, U$192: ADIN11100
U$5, U$69, U$105, U$141, U$177, U$213: DIGIKEY_LOGO
U$6, U$55, U$92, U$128, U$164, U$200: #PWR#19
U$7, U$39, U$76, U$112, U$148, U$184: PWR0
U$8, U$43, U$80, U$116, U$152, U$188: SHLD11
U$9, U$54, U$91, U$127, U$163, U$199: #EWP#18
U$10, U$56, U$93, U$129, U$165, U$201: #LED0#20
U$11, U$52, U$89, U$125, U$161, U$197: #GND#16
U$12, U$53, U$90, U$126, U$162, U$198: #CAP#17
U$13, U$59, U$96, U$132, U$168, U$204: ##TX2P4_EN##4
U$14, U$44, U$81, U$117, U$153, U$189: #SPI_CFG1#0
U$15, U$45, U$82, U$118, U$154, U$190: #MS_SEL#2
U$16, U$46, U$83, U$119, U$155, U$191: #SPI_CFG0#0
U$17, U$18, U$61, U$62, U$98, U$99, U$134, U$135, U$170, U$171, U$206, U$207: SINGLE_PAIR_ETHERNET0
U$19, U$72, U$108, U$144, U$180, U$216: WURTH_LOGO; WURTH_LOGO_9MM
U$20, U$64, U$100, U$136, U$172, U$208: ANALOG_DEVICE_LOGO_9MM
U$22, U$60, U$97, U$133, U$169, U$205: ##SWPD_EN##4
U$23, U$49, U$86, U$122, U$158, U$194: LED_03
U$24, U$26, U$40, U$48, U$77, U$85, U$113, U$121, U$149, U$157, U$185, U$193: FUNCTION0
U$25, U$50, U$87, U$123, U$159, U$195: LED_14
U$27, U$51, U$88, U$124, U$160, U$196: LINK_ST15
U$28, U$38, U$75, U$111, U$147, U$183: #MEAS#3
U$29, U$57, U$94, U$130, U$166, U$202: #LED1#21
U$30, U$65, U$101, U$137, U$173, U$209: HARTING_LOGO_9MM
U$31, U$58, U$95, U$131, U$167, U$203: #LINKST#2
U$32, U$66, U$102, U$138, U$174, U$210: WURTH_LOGO_9MM
U$33, U$70, U$106, U$142, U$178, U$214: ANALOG_DEVICES_LOGO; ANALOG_DEVICE_LOGO_9MM
U$34, U$67, U$103, U$139, U$175, U$211: DIGIKEY_LOGO
U$35, U$68, U$104, U$140, U$176, U$212: SFE_LOGO_NAME_FLAME_.1
Y1, Y2, Y3, Y4, Y5, Y6: 25MHz; CRYSTAL-SMD-2.0X1.6MM-WE

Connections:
1.1V: C11.1, C15.1, U1.23, U1.24
1.1V1: C31.1, C35.1, U7.23, U7.24
1.1V2: C54.1, C58.1, U11.23, U11.24
1.1V3: C77.1, C81.1, U15.23, U15.24
1.1V4: C100.1, C104.1, U19.23, U19.24
1.1V5: C123.1, C127.1, U23.23, U23.24
3.3V: C4.1, C9.1, C10.1, C12.1, C13.1, C14.1, C16.1, C17.1, LED-PWR.2, R8.1, R10.2, R11.1, R12.2, R13.2, R14.2, R15.2, R16.2, R17.2, R18.2, R20.1, R24.2, R25.2, R28.2, TP1.1, U1.16, U1.17, U1.22, U1.35, U2.8, U3.5
3.3V1: C26.1, C29.1, C30.1, C32.1, C33.1, C34.1, C36.1, C37.1, LED-PWR1.2, R32.1, R36.2, R37.1, R38.2, R39.2, R40.2, R41.2, R42.2, R43.2, R44.1, R45.2, R53.2, R54.2, R57.2, TP2.1, U5.8, U6.5, U7.16, U7.17, U7.22, U7.35
3.3V2: C49.1, C52.1, C53.1, C55.1, C56.1, C57.1, C59.1, C60.1, LED-PWR2.2, R61.1, R65.2, R66.1, R67.2, R68.2, R69.2, R70.2, R71.2, R72.2, R73.1, R74.2, R82.2, R83.2, R86.2, TP3.1, U9.8, U10.5, U11.16, U11.17, U11.22, U11.35
3.3V3: C72.1, C75.1, C76.1, C78.1, C79.1, C80.1, C82.1, C83.1, LED-PWR3.2, R90.1, R94.2, R95.1, R96.2, R97.2, R98.2, R99.2, R100.2, R101.2, R102.1, R103.2, R111.2, R112.2, R115.2, TP4.1, U13.8, U14.5, U15.16, U15.17, U15.22, U15.35
3.3V4: C95.1, C98.1, C99.1, C101.1, C102.1, C103.1, C105.1, C106.1, LED-PWR4.2, R119.1, R123.2, R124.1, R125.2, R126.2, R127.2, R128.2, R129.2, R130.2, R131.1, R132.2, R140.2, R141.2, R144.2, TP5.1, U17.8, U18.5, U19.16, U19.17, U19.22, U19.35
3.3V5: C118.1, C121.1, C122.1, C124.1, C125.1, C126.1, C128.1, C129.1, LED-PWR5.2, R148.1, R152.2, R153.1, R154.2, R155.2, R156.2, R157.2, R158.2, R159.2, R160.1, R161.2, R169.2, R170.2, R173.2, TP6.1, U21.8, U22.5, U23.16, U23.17, U23.22, U23.35
3.3V_IN: J2.73, R22.1
3.3V_IN1: J3.73, R30.1
3.3V_IN2: J5.73, R59.1
3.3V_IN3: J7.73, R88.1
3.3V_IN4: J9.73, R117.1
3.3V_IN5: J11.73, R146.1
!CS!: CS.1, J2.49, R25.1, U1.29
!CS!1: CS1.1, J3.49, R54.1, U7.29
!CS!2: CS2.1, J5.49, R83.1, U11.29
!CS!3: CS3.1, J7.49, R112.1, U15.29
!CS!4: CS4.1, J9.49, R141.1, U19.29
!CS!5: CS5.1, J11.49, R170.1, U23.29
!INT!: INT.1, J2.47, R24.1, U1.25
!INT!1: INT1.1, J3.47, R53.1, U7.25
!INT!2: INT2.1, J5.47, R82.1, U11.25
!INT!3: INT3.1, J7.47, R111.1, U15.25
!INT!4: INT4.1, J9.47, R140.1, U19.25
!INT!5: INT5.1, J11.47, R169.1, U23.25
!RESET!: J2.57, R29.1
!RESET!1: J3.57, R58.1
!RESET!2: J5.57, R87.1
!RESET!3: J7.57, R116.1
!RESET!4: J9.57, R145.1
!RESET!5: J11.57, R174.1
!SWPD_EN!: SWPD.1, U1.33
!SWPD_EN!1: SWPD1.1, U7.33
!SWPD_EN!2: SWPD2.1, U11.33
!SWPD_EN!3: SWPD3.1, U15.33
!SWPD_EN!4: SWPD4.1, U19.33
!SWPD_EN!5: SWPD5.1, U23.33
!TX2P4_EN!: TX2P4.1, U1.31
!TX2P4_EN!1: TX2P1.1, U7.31
!TX2P4_EN!2: TX2P2.1, U11.31
!TX2P4_EN!3: TX2P3.1, U15.31
!TX2P4_EN!4: TX2P5.1, U19.31
!TX2P4_EN!5: TX2P6.1, U23.31
A0: J2.36, U2.1
A1: J2.34, U2.2
A2: J2.32, U2.3
A3: J3.36, U5.1
A4: J3.32, U5.3
A5: J3.34, U5.2
A6: J5.36, U9.1
A7: J5.32, U9.3
A8: J5.34, U9.2
A9: J7.36, U13.1
A10: J7.32, U13.3
A11: J7.34, U13.2
A12: J9.36, U17.1
A13: J9.32, U17.3
A14: J9.34, U17.2
A15: J11.36, U21.1
A16: J11.32, U21.3
A17: J11.34, U21.2
DA+: J1.1, T1.7
DA+1: J4.1, T2.7
DA+2: J6.1, T3.7
DA+3: J8.1, T4.7
DA+4: J10.1, T5.7
DA+5: J12.1, T6.7
DA-: J1.2, T1.6
DA-1: J4.2, T2.6
DA-2: J6.2, T3.6
DA-3: J8.2, T4.6
DA-4: J10.2, T5.6
DA-5: J12.2, T6.6
EWP: EWP.2, J2.40, R8.2, U2.7
EWP1: EWP1.2, J3.40, R32.2, U5.7
EWP2: EWP2.2, J5.40, R61.2, U9.7
EWP3: EWP3.2, J7.40, R90.2, U13.7
EWP4: EWP4.2, J9.40, R119.2, U17.7
EWP5: EWP5.2, J11.40, R148.2, U21.7
GND: C3.2, C4.2, C5.2, C6.2, C7.2, C8.2, C9.2, C10.2, C11.2, C12.2, C13.2, C14.2, C15.2, C16.2, C17.2, C18.2, C19.2, C20.2, C21.2, C23.2, EWP.1, J2.1, J2.2, J2.8, J2.33, J2.39, J2.45, J2.75, J2.GND1, J2.GND2, J2.GND3, J2.GND4, J2.GND5, J2.GND6, PWR.C, Q1.2, R19.2, R21.1, S1.1, SHLD.1, U1.EP, U2.4, U3.2, U4.3, Y1.2, Y1.4
GND1: C24.2, C25.2, C26.2, C27.2, C28.2, C29.2, C30.2, C31.2, C32.2, C33.2, C34.2, C35.2, C36.2, C37.2, C38.2, C39.2, C42.2, C43.2, C44.2, C46.2, EWP1.1, J3.1, J3.2, J3.8, J3.33, J3.39, J3.45, J3.75, J3.GND1, J3.GND2, J3.GND3, J3.GND4, J3.GND5, J3.GND6, PWR1.C, Q4.2, R46.1, R47.2, S2.1, SHLD1.1, U5.4, U6.2, U7.EP, U8.3, Y2.2, Y2.4
GND2: C47.2, C48.2, C49.2, C50.2, C51.2, C52.2, C53.2, C54.2, C55.2, C56.2, C57.2, C58.2, C59.2, C60.2, C61.2, C62.2, C65.2, C66.2, C67.2, C69.2, EWP2.1, J5.1, J5.2, J5.8, J5.33, J5.39, J5.45, J5.75, J5.GND1, J5.GND2, J5.GND3, J5.GND4, J5.GND5, J5.GND6, PWR2.C, Q6.2, R75.1, R76.2, S3.1, SHLD2.1, U9.4, U10.2, U11.EP, U12.3, Y3.2, Y3.4
GND3: C70.2, C71.2, C72.2, C73.2, C74.2, C75.2, C76.2, C77.2, C78.2, C79.2, C80.2, C81.2, C82.2, C83.2, C84.2, C85.2, C88.2, C89.2, C90.2, C92.2, EWP3.1, J7.1, J7.2, J7.8, J7.33, J7.39, J7.45, J7.75, J7.GND1, J7.GND2, J7.GND3, J7.GND4, J7.GND5, J7.GND6, PWR3.C, Q8.2, R104.1, R105.2, S4.1, SHLD3.1, U13.4, U14.2, U15.EP, U16.3, Y4.2, Y4.4
GND4: C93.2, C94.2, C95.2, C96.2, C97.2, C98.2, C99.2, C100.2, C101.2, C102.2, C103.2, C104.2, C105.2, C106.2, C107.2, C108.2, C111.2, C112.2, C113.2, C115.2, EWP4.1, J9.1, J9.2, J9.8, J9.33, J9.39, J9.45, J9.75, J9.GND1, J9.GND2, J9.GND3, J9.GND4, J9.GND5, J9.GND6, PWR4.C, Q10.2, R133.1, R134.2, S5.1, SHLD4.1, U17.4, U18.2, U19.EP, U20.3, Y5.2, Y5.4
GND5: C116.2, C117.2, C118.2, C119.2, C120.2, C121.2, C122.2, C123.2, C124.2, C125.2, C126.2, C127.2, C128.2, C129.2, C130.2, C131.2, C134.2, C135.2, C136.2, C138.2, EWP5.1, J11.1, J11.2, J11.8, J11.33, J11.39, J11.45, J11.75, J11.GND1, J11.GND2, J11.GND3, J11.GND4, J11.GND5, J11.GND6, PWR5.C, Q12.2, R162.1, R163.2, S6.1, SHLD5.1, U21.4, U22.2, U23.EP, U24.3, Y6.2, Y6.4
I2C_SCL: J2.21, U2.6
I2C_SCL1: J3.21, U5.6
I2C_SCL2: J5.21, U9.6
I2C_SCL3: J7.21, U13.6
I2C_SCL4: J9.21, U17.6
I2C_SCL5: J11.21, U21.6
I2C_SDA: J2.19, U2.5
I2C_SDA1: J3.19, U5.5
I2C_SDA2: J5.19, U9.5
I2C_SDA3: J7.19, U13.5
I2C_SDA4: J9.19, U17.5
I2C_SDA5: J11.19, U21.5
LED_0: LED-0.2, U1.3
LED_1: LED-1.2, U1.6
LED_2: LED-2.2, U7.6
LED_3: LED-3.2, U7.3
LED_4: LED-4.2, U11.6
LED_5: LED-5.2, U11.3
LED_6: LED-6.2, U15.6
LED_7: LED-7.2, U15.3
LED_8: LED-8.2, U19.6
LED_9: LED-9.2, U19.3
LED_10: LED-10.2, U23.6
LED_11: LED-11.2, U23.3
LINK_ST: LED-LINK.2, U1.4
LINK_ST1: LED-LINK1.2, U7.4
LINK_ST2: LED-LINK2.2, U11.4
LINK_ST3: LED-LINK3.2, U15.4
LINK_ST4: LED-LINK4.2, U19.4
LINK_ST5: LED-LINK5.2, U23.4
MS_SEL: MS_SEL.1, U1.30
MS_SEL1: MS_SEL1.1, U7.30
MS_SEL2: MS_SEL2.1, U11.30
MS_SEL3: MS_SEL3.1, U15.30
MS_SEL4: MS_SEL4.1, U19.30
MS_SEL5: MS_SEL5.1, U23.30
unnamed: MEAS.1, MEAS.3, Q2.3
unnamed: C3.1, C8.1, MEAS.2, MEAS.4, U3.1
unnamed: C21.1, T1.5
unnamed: C22.1, T1.4
unnamed: LED-LINK.1, LINK_ST.A, R19.1
unnamed: LED-1.1, LED_1.C, R18.1
unnamed: C22.2, R23.1, T1.3
unnamed: C20.1, R23.2
unnamed: LED-0.1, LED_0.C, R17.1
unnamed: Q1.3, R26.1
unnamed: Q2.1, R7.1, R26.2
unnamed: C5.1, U1.8, Y1.1
unnamed: C23.1, R27.1, U1.5
unnamed: C6.1, U1.9, Y1.3
unnamed: R27.2, R28.1, R29.2, S1.3
unnamed: C24.1, C25.1, MEAS1.2, MEAS1.4, U6.1
unnamed: MEAS1.1, MEAS1.3, Q3.3
unnamed: R10.1, U1.26
unnamed: LED-PWR.1, R9.2
unnamed: PWR.A, R9.1
unnamed: C18.1, U1.19
unnamed: C19.1, U1.20
unnamed: LED_0.A, R11.2
unnamed: C1.1, R2.1, R4.1, U4.2, U4.5
unnamed: MS_SEL.2, R14.1
unnamed: R13.1, SWPD.2
unnamed: R12.1, TX2P4.2
unnamed: R16.1, SPI_CFG0.2
unnamed: R15.1, SPI_CFG1.2
unnamed: LED_1.A, R20.2
unnamed: C2.1, R1.1, R3.2, U4.1, U4.6
unnamed: C1.2, T1.1
unnamed: LINK_ST.C, R21.2
unnamed: C2.2, T1.2
unnamed: R4.2, R6.2, U1.13
unnamed: R3.1, R5.1, U1.14
unnamed: R1.2, R6.1, U1.15
unnamed: R2.2, R5.2, U1.12
unnamed: Q3.1, R31.1, R55.2
unnamed: LED-PWR1.1, R33.2
unnamed: C7.1, SHLD.3
unnamed: PWR1.A, R33.1
unnamed: J1.S1, J1.S2, J1.S3, J1.S4, SHLD.2
unnamed: C27.1, U7.8, Y2.1
unnamed: C28.1, U7.9, Y2.3
unnamed: R56.2, R57.1, R58.2, S2.3
unnamed: R36.1, U7.26
unnamed: C38.1, U7.19
unnamed: C39.1, U7.20
unnamed: MS_SEL1.2, R40.1
unnamed: R39.1, SWPD1.2
unnamed: R38.1, TX2P1.2
unnamed: R42.1, SPI_CFG3.2
unnamed: R41.1, SPI_CFG2.2
unnamed: LED_2.A, R37.2
unnamed: LED_3.A, R44.2
unnamed: LINK_ST1.C, R46.2
unnamed: C41.1, R34.1, R50.1, U8.2, U8.5
unnamed: C40.1, R35.1, R51.2, U8.1, U8.6
unnamed: R49.2, R50.2, U7.13
unnamed: R48.1, R51.1, U7.14
unnamed: R35.2, R49.1, U7.15
unnamed: R34.2, R48.2, U7.12
unnamed: C41.2, T2.1
unnamed: C40.2, T2.2
unnamed: C42.1, SHLD1.3
unnamed: J4.S1, J4.S2, J4.S3, J4.S4, SHLD1.2
unnamed: C44.1, T2.5
unnamed: C45.1, T2.4
unnamed: C45.2, R52.1, T2.3
unnamed: C43.1, R52.2
unnamed: LED-LINK1.1, LINK_ST1.A, R47.1
unnamed: LED-2.1, LED_3.C, R45.1
unnamed: LED-3.1, LED_2.C, R43.1
unnamed: Q4.3, R55.1
unnamed: C46.1, R56.1, U7.5
unnamed: C47.1, C48.1, MEAS2.2, MEAS2.4, U10.1
unnamed: MEAS2.1, MEAS2.3, Q5.3
unnamed: Q5.1, R60.1, R84.2
unnamed: LED-PWR2.1, R62.2
unnamed: PWR2.A, R62.1
unnamed: C50.1, U11.8, Y3.1
unnamed: C51.1, U11.9, Y3.3
unnamed: R85.2, R86.1, R87.2, S3.3
unnamed: R65.1, U11.26
unnamed: C61.1, U11.19
unnamed: C62.1, U11.20
unnamed: MS_SEL2.2, R69.1
unnamed: R68.1, SWPD2.2
unnamed: R67.1, TX2P2.2
unnamed: R71.1, SPI_CFG5.2
unnamed: R70.1, SPI_CFG4.2
unnamed: LED_4.A, R66.2
unnamed: LED_5.A, R73.2
unnamed: LINK_ST2.C, R75.2
unnamed: C64.1, R63.1, R79.1, U12.2, U12.5
unnamed: C63.1, R64.1, R80.2, U12.1, U12.6
unnamed: R78.2, R79.2, U11.13
unnamed: R77.1, R80.1, U11.14
unnamed: R64.2, R78.1, U11.15
unnamed: R63.2, R77.2, U11.12
unnamed: C64.2, T3.1
unnamed: C63.2, T3.2
unnamed: C65.1, SHLD2.3
unnamed: J6.S1, J6.S2, J6.S3, J6.S4, SHLD2.2
unnamed: C67.1, T3.5
unnamed: C68.1, T3.4
unnamed: C68.2, R81.1, T3.3
unnamed: C66.1, R81.2
unnamed: LED-LINK2.1, LINK_ST2.A, R76.1
unnamed: LED-4.1, LED_5.C, R74.1
unnamed: LED-5.1, LED_4.C, R72.1
unnamed: Q6.3, R84.1
unnamed: C69.1, R85.1, U11.5
unnamed: C70.1, C71.1, MEAS3.2, MEAS3.4, U14.1
unnamed: MEAS3.1, MEAS3.3, Q7.3
unnamed: Q7.1, R89.1, R113.2
unnamed: LED-PWR3.1, R91.2
unnamed: PWR3.A, R91.1
unnamed: C73.1, U15.8, Y4.1
unnamed: C74.1, U15.9, Y4.3
unnamed: R114.2, R115.1, R116.2, S4.3
unnamed: R94.1, U15.26
unnamed: C84.1, U15.19
unnamed: C85.1, U15.20
unnamed: MS_SEL3.2, R98.1
unnamed: R97.1, SWPD3.2
unnamed: R96.1, TX2P3.2
unnamed: R100.1, SPI_CFG7.2
unnamed: R99.1, SPI_CFG6.2
unnamed: LED_6.A, R95.2
unnamed: LED_7.A, R102.2
unnamed: LINK_ST3.C, R104.2
unnamed: C87.1, R92.1, R108.1, U16.2, U16.5
unnamed: C86.1, R93.1, R109.2, U16.1, U16.6
unnamed: R107.2, R108.2, U15.13
unnamed: R106.1, R109.1, U15.14
unnamed: R93.2, R107.1, U15.15
unnamed: R92.2, R106.2, U15.12
unnamed: C87.2, T4.1
unnamed: C86.2, T4.2
unnamed: C88.1, SHLD3.3
unnamed: J8.S1, J8.S2, J8.S3, J8.S4, SHLD3.2
unnamed: C90.1, T4.5
unnamed: C91.1, T4.4
unnamed: C91.2, R110.1, T4.3
unnamed: C89.1, R110.2
unnamed: LED-LINK3.1, LINK_ST3.A, R105.1
unnamed: LED-6.1, LED_7.C, R103.1
unnamed: LED-7.1, LED_6.C, R101.1
unnamed: Q8.3, R113.1
unnamed: C92.1, R114.1, U15.5
unnamed: C93.1, C94.1, MEAS4.2, MEAS4.4, U18.1
unnamed: MEAS4.1, MEAS4.3, Q9.3
unnamed: Q9.1, R118.1, R142.2
unnamed: LED-PWR4.1, R120.2
unnamed: PWR4.A, R120.1
unnamed: C96.1, U19.8, Y5.1
unnamed: C97.1, U19.9, Y5.3
unnamed: R143.2, R144.1, R145.2, S5.3
unnamed: R123.1, U19.26
unnamed: C107.1, U19.19
unnamed: C108.1, U19.20
unnamed: MS_SEL4.2, R127.1
unnamed: R126.1, SWPD4.2
unnamed: R125.1, TX2P5.2
unnamed: R129.1, SPI_CFG9.2
unnamed: R128.1, SPI_CFG8.2
unnamed: LED_8.A, R124.2
unnamed: LED_9.A, R131.2
unnamed: LINK_ST4.C, R133.2
unnamed: C110.1, R121.1, R137.1, U20.2, U20.5
unnamed: C109.1, R122.1, R138.2, U20.1, U20.6
unnamed: R136.2, R137.2, U19.13
unnamed: R135.1, R138.1, U19.14
unnamed: R122.2, R136.1, U19.15
unnamed: R121.2, R135.2, U19.12
unnamed: C110.2, T5.1
unnamed: C109.2, T5.2
unnamed: C111.1, SHLD4.3
unnamed: J10.S1, J10.S2, J10.S3, J10.S4, SHLD4.2
unnamed: C113.1, T5.5
unnamed: C114.1, T5.4
unnamed: C114.2, R139.1, T5.3
unnamed: C112.1, R139.2
unnamed: LED-LINK4.1, LINK_ST4.A, R134.1
unnamed: LED-8.1, LED_9.C, R132.1
unnamed: LED-9.1, LED_8.C, R130.1
unnamed: Q10.3, R142.1
unnamed: C115.1, R143.1, U19.5
unnamed: C116.1, C117.1, MEAS5.2, MEAS5.4, U22.1
unnamed: MEAS5.1, MEAS5.3, Q11.3
unnamed: Q11.1, R147.1, R171.2
unnamed: LED-PWR5.1, R149.2
unnamed: PWR5.A, R149.1
unnamed: C119.1, U23.8, Y6.1
unnamed: C120.1, U23.9, Y6.3
unnamed: R172.2, R173.1, R174.2, S6.3
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

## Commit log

2021-11-22 SCH import and some preliminary part placement
    [SparkFun_MicroMod_Function_ADIN1110.brd, SparkFun_MicroMod_Function_ADIN1110.sch]
2021-11-29 HARTING T1 connector added and layout work
    [SparkFun_MicroMod_Function_ADIN1110.brd, SparkFun_MicroMod_Function_ADIN1110.sch]
2021-11-30 sch cleanup
    [SparkFun_MicroMod_Function_ADIN1110.brd, SparkFun_MicroMod_Function_ADIN1110.sch]
2021-12-01 some checklist catches - sch cleanup
    [SparkFun_MicroMod_Function_ADIN1110.brd, SparkFun_MicroMod_Function_ADIN1110.sch]
2021-12-03 Added transformer isolation and TVS diode array
    [SparkFun_MicroMod_Function_ADIN1110.brd, SparkFun_MicroMod_Function_ADIN1110.sch]
2021-12-13 Prototype Design Review Changes
    -Moved LEDs to upper edge.
    -Backed off GND pour from connector for better isolation
    -added jumpers to disable each LED if desired
    -Schematic symbols cleanup and note corrections
    -moved 3.3V testpoint to match other Ethernet MM board.
    -tightened FP drills on T1 connector
    [SparkFun_MicroMod_Function_ADIN1110.brd, SparkFun_MicroMod_Function_ADIN1110.sch]
2021-12-16 checklist catches
    -added CS and INT pulllups
    -nudged vias to avoid silk
    -added 1/2/3/4 text objects to help indicate 4 layers
    -added suggested Selective Solder path on layer 48
    -adjusted tnames for better assembly sheet
    -added measures
    -corrected active low labels on some bottom config jumpers
    [SparkFun_MicroMod_Function_ADIN1110.brd, SparkFun_MicroMod_Function_ADIN1110.sch]
2021-12-16 connected RESET to MM GPIO (F5)
    -needed for testing, but also could be useful for the user to perform a hard reset on the ANIN1110 from GPIO controlled on their MM main board.
    [SparkFun_MicroMod_Function_ADIN1110.brd, SparkFun_MicroMod_Function_ADIN1110.sch]
2021-12-17 Final tweaks before ordering protos
    -pulled GND back out to LEDS
    -reverted back to T1 connector max tolerance drill size
    -added connector width to measures
    [SparkFun_MicroMod_Function_ADIN1110.brd, SparkFun_MicroMod_Function_ADIN1110.sch]
2021-12-17 Prototype Panel
    [SparkFun_MicroMod_Function_ADIN1110-Panel_v01d.GBL, SparkFun_MicroMod_Function_ADIN1110-Panel_v01d.GBO, SparkFun_MicroMod_Function_ADIN1110-Panel_v01d.GBP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]
2022-01-06 Wurth Electronik caps
    [SparkFun_MicroMod_Function_ADIN1110.brd, SparkFun_MicroMod_Function_ADIN1110.sch]
2022-01-07 LEDs and Xtal swapped out for Wurth Electronic Parts
    Also bumped version to v10, because the WE xtal has GND pads, and new package has polarity dot.
    [SparkFun_MicroMod_Function_ADIN1110.brd, SparkFun_MicroMod_Function_ADIN1110.sch]
2022-01-13 Switched C21 from 0402 to 0603 package
    Due to sourcing issues.
    [SparkFun_MicroMod_Function_ADIN1110.brd, SparkFun_MicroMod_Function_ADIN1110.sch]
2022-01-14 Add Prod_IDs to T1 connectors
    updated single and panel brd files
    [SparkFun_MicroMod_Function_ADIN1110-Panel_v01d.brd, SparkFun_MicroMod_Function_ADIN1110.brd, SparkFun_MicroMod_Function_ADIN1110.sch]
2022-01-17 R3, R4, R5, R6 to in-house PROD_IDs
    Note, these values are very slightly different than the ones in the DS sch.
    [SparkFun_MicroMod_Function_ADIN1110.brd, SparkFun_MicroMod_Function_ADIN1110.sch]
2022-01-17 Update PROD_IDs for 10ohm and 4.7ohm resistors on production panel
    [SparkFun_MicroMod_Function_ADIN1110-Panel_v01d.brd]
2022-02-07 TVS diode placement and more
    -Moved TVS diodes to "IC" side of DA-/DA+ DC coupling caps
    -Added debounce to reset button
    -Routed through pads 5 and 6 on TVS diode package.
    -Added R29 to avoid damaging GPIO if set to output low and button pressed
    -Added R26 to mosfet gate control line to avoid potential overvoltage/ringing
    -Re-arranged caps so smalled value decoupling caps are closest to pins on IC.
    -moved to "v10" in brd and sch
    -C22 changed to 470nF to improove droop performance
    [SparkFun_MicroMod_Function_ADIN1110.brd, SparkFun_MicroMod_Function_ADIN1110.sch]
2022-02-08 470pF cap to 0805 with new PROD_ID
    -new 470nF cap had to bump up to 0805 for the 100V rating in that value
    -Voltage specs in part values
    [SparkFun_MicroMod_Function_ADIN1110.brd, SparkFun_MicroMod_Function_ADIN1110.sch]
2022-02-24 SPI test points and moved config jumpers
    -moved bottom config jumpers to avoid reflections on CIPO
    -added SPI test points
    [SparkFun_MicroMod_Function_ADIN1110.brd, SparkFun_MicroMod_Function_ADIN1110.sch]
2022-02-25 Renaming CIPO/COPI to POCI/PICO
    [SparkFun_MicroMod_Function_ADIN1110.brd, SparkFun_MicroMod_Function_ADIN1110.sch]
2022-02-25 Adjusted inner layer to match top/bottom copper
    -Now the inner layers "back away" from the connector and transformer exactly the same as the top and bottom layers.
    [SparkFun_MicroMod_Function_ADIN1110.brd]
2022-03-03 Production panel and gerbers v10d
    [SparkFun_MicroMod_Function_ADIN1110-Panel_v01d.GBL, SparkFun_MicroMod_Function_ADIN1110-Panel_v01d.GBO, SparkFun_MicroMod_Function_ADIN1110-Panel_v01d.GBP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]
2022-03-11 PROD_ID for 0.68uF 0603 Cap (C11)
    [SparkFun_MicroMod_Function_ADIN1110.brd, SparkFun_MicroMod_Function_ADIN1110.sch]
2022-03-11 added PROD_IDs to all 0.68uF caps on panel file
    [SparkFun_MicroMod_Function_ADIN1110-Panel_v10d.brd]
2022-03-30 Silk updated to "Single Pair Ethernet"
    -updated product name silk
    -bumped version to v11 in brd and sch
    [SparkFun_MicroMod_Function_ADIN1110.brd, SparkFun_MicroMod_Function_ADIN1110.sch]
2022-03-31 reduced width by 0.01" on each side
    -This will help avoid overlap issues when plugging in two of these boards into the main-double.
    [SparkFun_MicroMod_Function_ADIN1110.brd, SparkFun_MicroMod_Function_ADIN1110.sch]
2022-04-01 Panel for v11
    [SparkFun_MicroMod_Function_ADIN1110-Panel_v10d.brd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]
2022-04-20 R27 changed to 4.7K
    -updated prod_id and values on boat single and panel files.
    [SparkFun_MicroMod_Function_ADIN1110-Panel_v11.brd, SparkFun_MicroMod_Function_ADIN1110.brd, SparkFun_MicroMod_Function_ADIN1110.sch]
2022-04-21 Updated Measures to match actual new width
    [SparkFun_MicroMod_Function_ADIN1110.brd]
2022-06-23 v12 - partner logos added
    [SparkFun_MicroMod_Function_ADIN1110.brd, SparkFun_MicroMod_Function_ADIN1110.sch]
2022-06-27 Removed v11 panel and added v12 panel
    [SparkFun_MicroMod_Function_ADIN1110-Panel_v11.GBL, SparkFun_MicroMod_Function_ADIN1110-Panel_v11.GBO, SparkFun_MicroMod_Function_ADIN1110-Panel_v11.GTL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]

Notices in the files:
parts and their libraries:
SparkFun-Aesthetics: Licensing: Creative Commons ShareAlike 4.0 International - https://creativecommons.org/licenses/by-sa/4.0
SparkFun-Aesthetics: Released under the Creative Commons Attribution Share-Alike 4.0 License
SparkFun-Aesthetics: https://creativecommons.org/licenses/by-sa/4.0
